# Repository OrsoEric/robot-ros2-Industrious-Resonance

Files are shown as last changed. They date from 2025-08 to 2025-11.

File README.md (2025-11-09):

# robot-ros2-Industrious-Resonance
Constructing a ROS2 robot to experiment with using LLMs as poors man AGI. 

# SPECS

- moving by sunday 2025-08-24 
- uses the raspberry pi
    - runs Ubuntu 22
    - runs ROS2
- uses OrangeHat
- uses 18650 battieries
- sensors
    - Raspicam
    - Microphone
- actuators    
    - two main motors
    - Loudspeaker
- options:
    - screen

# Old Robots

Census of old robots

## JetBot-00 (2021-09)

This is a robot I assembled to test the Jetson Nano.

It powered up, moved motors has screen and a supply. I should disassemble it, the Jetson Nano is too small to run competent AI with 2GB RAM. The Jetson Nano also uses a custom linux with binary blobs and not a real linux.

2021-09-JetBot-00-TOP

2021-09-JetBot-00-BOT

I can technically mount a raspberry and make a robot out of it.

## OrangeBot (2020-10)

Large robot for the Pi Wars with DC Motors with Encoders. It's high spec but not suitable for this project.

OrangeBot Pi Wars 2020

## Unnamed Lego Robot

This is a good effort to make a raspberry pi lego robot.

Unnamed Lego Robot

# ROBOT 

I choose to start from the LEGO robot, it should be very close to working

## Mechanical

Using OpenSCAD to design the base

### Ball Holder

As pivot wheel, I think of using a 40mm tennis ball. I can make a 3D printed structure to hold it with low friction, I'm thinking of three holding arms and three structural arms. I went with OpenSCAD to make it



https://github.com/user-attachments/assets/4e690c88-9136-435e-aecc-3a0f2ad5ae8a

### Servo Holder

I reused some of my previous work but decided I should do pillars without overhangs since I'm printing them on the robot platform



### Shell

Using Flux to generate possible images for the shell

Below is an idea I like that plays on the industrious resonance name, a shell that is weavy with interference patterns and a frontal lens

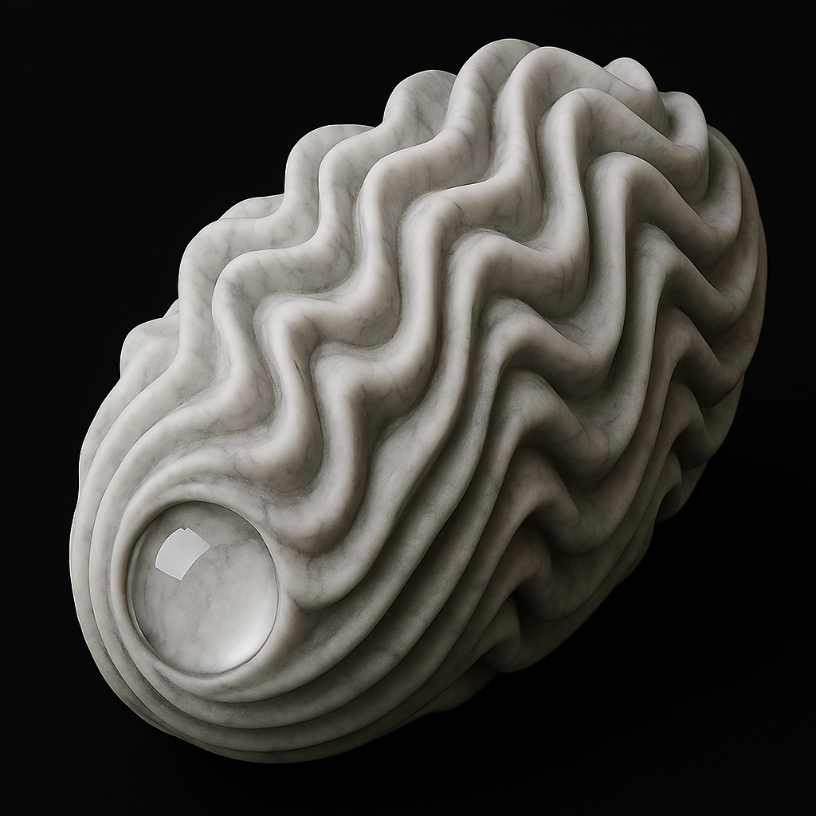
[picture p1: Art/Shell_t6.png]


### Platform



### Assembly 

Place a raspberry, batteries and servomotors on an ellipse



Considerations
- I switch to a Latte Panda MU to improve on LLM performance
- In the future I do a proper LPMU carry board
- I need to think of battery holder

Base is a rectangle with tounded corner. Developed servo pillars, used 18650 battery holder and ping pong ball holder for pivot.



With the Lattepanda Mu electronics on top and base properly resized to carry it



Considerations:
- Batteries are hard to reach, I'd like bottom facing battery holder, but how would supports work?
- I need a camara stand
- I need lips to attach a shell, or a border
- I need to decide on the electronics and spaces to platce that electronics
- I need to improve on the LPMU pillars, I need to make them through hole to the bottom
- I need a power switch

---

Lots of work on the robot
- 18650 inverse holder 2S2P, connected 4S1P
- border
- hole for switch
- support for regulator PCB
- hex nuts below for the lattepanda

I printed it in opaline PETG with supports, it came out really well! Tollerances for the battery holders are perfect!



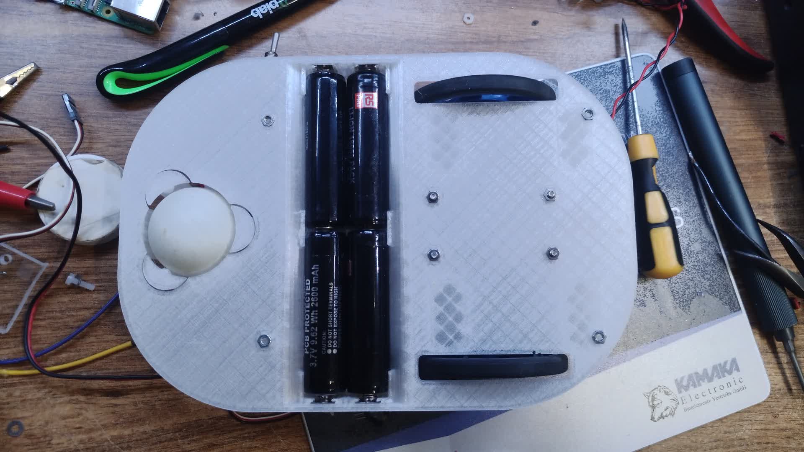
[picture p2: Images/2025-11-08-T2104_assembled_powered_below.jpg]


Video of the assembly Process

[Github is incompetently made and I have no way to embed a video bigger than 10MB](https://github.com/orgs/community/discussions/19403)

The video will work when you fork and open with VS Code with the preview MD. Otherwise download it and watch it.

[Link to the video of the assembly process of the battery and regulator](/Videos/2025-11-08-T2103_assembly_battery_regulator_480p.mp4)

## Electronics

### Raspberry Pi

It uses an OrangeHat, I remember it has a screen, UART, reset, and SERVO interpolation, it should be good to do a two axis rotation. It has an IMU, and the front numbers show change when I move it, it might be working!

I remember that if the OS isn't running, it keeps reset the OrangeHat and it stays offline, it's a deliberate design decision that works, it's why it wasn't showing anything.

Power regulator is good.

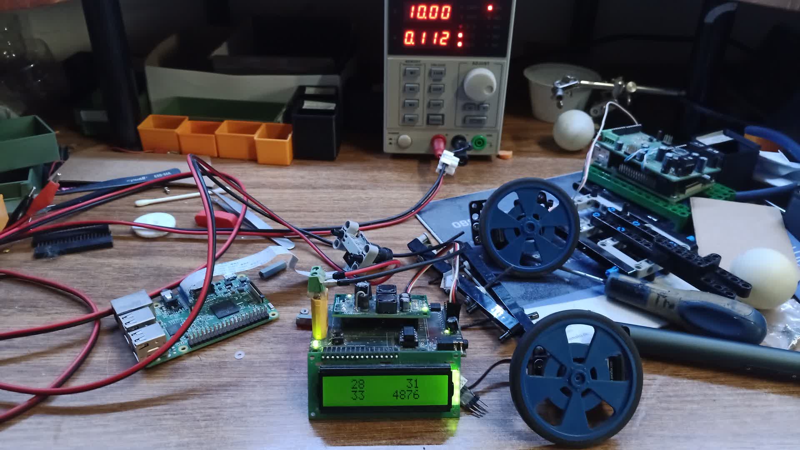
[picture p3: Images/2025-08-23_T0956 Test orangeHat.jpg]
Test OrangeHat Electronics


### Lattepanda Mu

Using the Lattepanda Mu I need a different electronics setup

I think I'll do a Longan Nano because of the screen, use one of my regulators, and an adapter to connect the servomotors. Feels like a good experimental setup without committing too much

I would like encoders on the motors...

### Servomotors - Longan Nano

I need a board to move the servomotors and have a screen.

First choice was the Longan Nano, it's compact, powerful and has a nice screen and I deed lots of drivers.

[Longan Nano](https://fatherofmachines.blogspot.com/p/longan-nano-gd32vf103.html)

I tried and it's bricked on Platform IO. I can probably make it work.

[](/log-longan-nano.md)

### Servomotors - AT324PA

I made useful boards based on AT324 and others, the one from Unit Zero has already the servo adapters and works fine.

[Install Microchip Studio](https://www.microchip.com/en-us/tools-resources/develop/microchip-studio#Downloads), open project, recompile and upload, everything works!

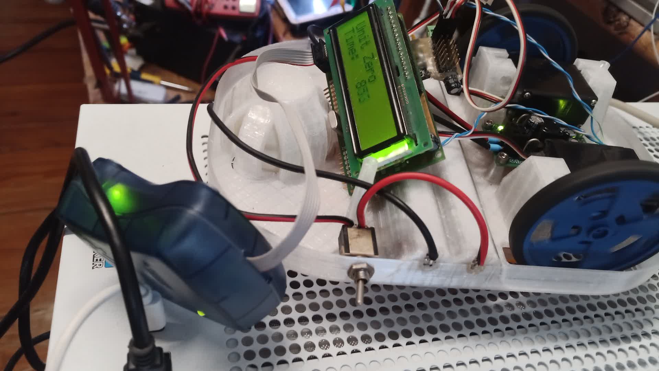
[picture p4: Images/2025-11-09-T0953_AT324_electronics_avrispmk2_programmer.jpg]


From here I need a firmware with the parser and uart in order to control it from an SBC

I'm thinking of doing it simple, possibly a mov speed duration instruction, that is very easy for the MCP server to produce, even if not very useful for doing useful applications. This is just an MVP.

## Firmware

SPECS:
- UART link
- Parser
- Ability to move servos
- Ability to display text on the screen

### Seesaw

Make a demo to move at seesaw speed the two wheels

<video src="https://github.com/user-attachments/assets/5bb4f36e-5e4b-4e43-b68f-162d931d1378" width="720" height="480"></video>

### Serial Commands

OrangeHat is programmed with the following functions

```
ARG_S8 = 's',
ARG_U8 = 'u',
ARG_S16 = 'S',
ARG_U16 = 'U',
ARG_U32 = 'D',
ARG_S32 = 'd'

//Register ping command. It's used to reset the communication timeout
f_ret = parser_tmp.add_cmd( "P", (void *)&ping_handler );
//Register the Find command. Board answers with board signature
f_ret |= parser_tmp.add_cmd( "F", (void *)&send_signature_handler );
//Platform set PPM command
f_ret |= parser_tmp.add_cmd( "PPM%u:%S:%S", (void *)&set_servo_ppm );
```

### Protocol

---

## Operating System and Raspicam Streaming

Now I need to choose a Raspberry and setup the OS.

I do have a Raspberry with Hailo 8L and raspiocam streaming already setup, test that instead, it saves lots of work!

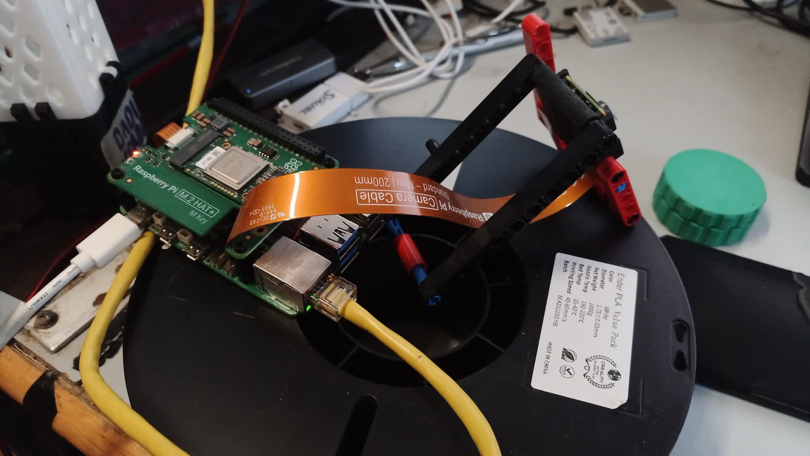
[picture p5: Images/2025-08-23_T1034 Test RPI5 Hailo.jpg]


Power is good, now try with ping, putty and launching the streaming demo and enumerating the Hailo

- ETH0 (static): 192.168.1.65 
- User: raspi
- Password: raspi

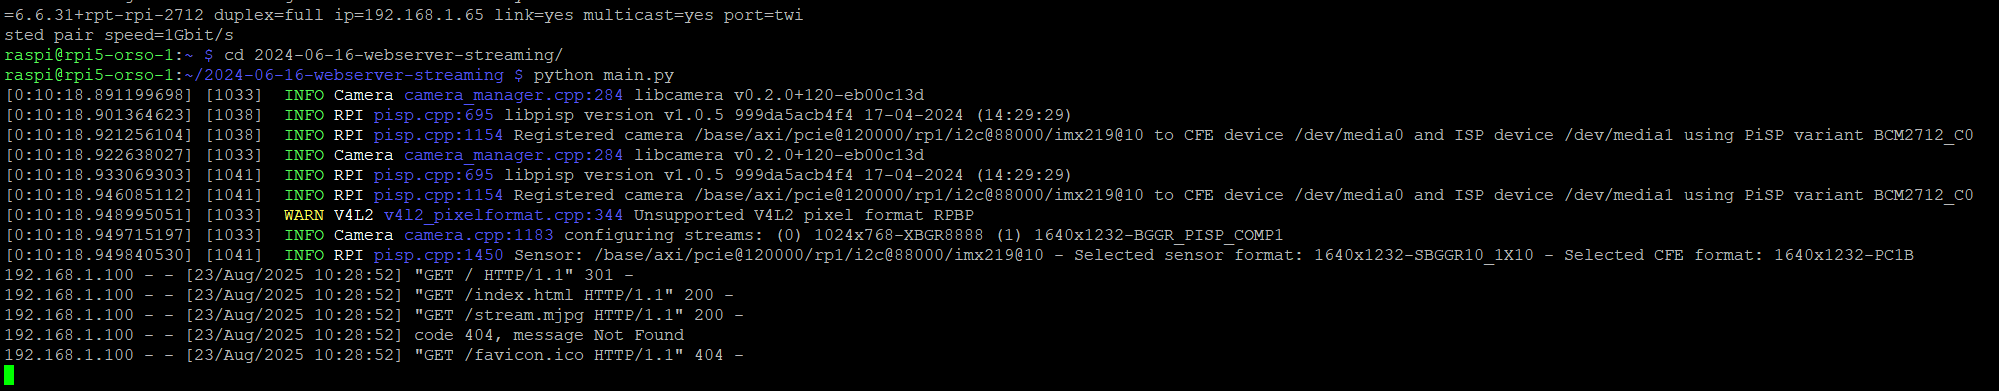
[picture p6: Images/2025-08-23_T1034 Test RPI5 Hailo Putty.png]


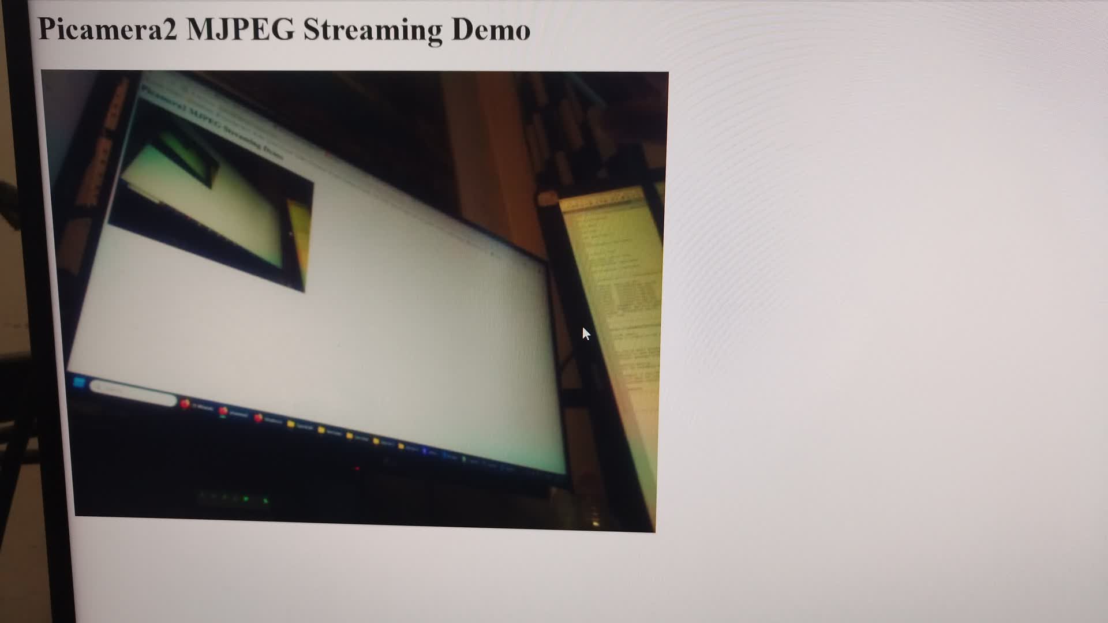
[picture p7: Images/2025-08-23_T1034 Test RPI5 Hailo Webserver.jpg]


TODO: Do I really want to move to Ubuntu and have ROS2? If I'm already good like this perhaps I should drop the ROS2 requirement

### Raspberry Pi 5

Test that the power supply is good
- 10V 0.5A streaming with camera and connected via webserver

Connect with VS Code Remote

Make an application that clears the reset

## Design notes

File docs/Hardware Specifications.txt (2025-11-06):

Mu Lite Board

Latte Panda Mu

N100
https://www.techpowerup.com/cpu-specs/processor-n100.c3007

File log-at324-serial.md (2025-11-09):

# Serial

Connecting the AT324 to the computer was more trouble than expected

Windows 11 is incompetently designed and doen't load the driver

Key registers didn't help, doesn't load the driver

Two of my adapters don't work

Luckily the FTDI 232 does have a WIN11 blessed driver

[Blessed driver for FTDI232](https://ftdichip.com/drivers/)

Connecting the AT324 to the robot regulator, the programmer, the scope and the FTDI chip to the computer. Using UART0 PD1 TXO to send



Checking with scope that it works



FTDI chip



Checking rx and tx. Sent SHAKA, and the firmware does send it back one at a time, I'm unloading it slowly for some reason, that's fine it's just done quick to work, the peripheral drivers I wrote a long while ago seems to work!



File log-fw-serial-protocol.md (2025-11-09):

# Serial Protocol

The scope of the protocol is to let the SBC send motion commands

It's meant to be compiled by a MCP server

So I'd like to have a sort of queue of commands, I am thinking speed duration

## Maze Runner

Below is the dictionary I used for Maze Runner

```cpp
//Command dictionary. Command IDs 0 and 255 are forbidden
U8 uart_cmd[] =
{
	//Ping: No action. Effect is to reset the connection timeout
	UART_CMD_PING		, 'P', '\0',
	//Sign: Ask for board signature
	UART_CMD_SIGN		, 'F', '\0',
	//Set Speed: R right engine L left engine
	UART_CMD_SETVEL	, 'V', 'R', '%', 'd', 'L', '%', 'd', '\0',
	//Dictionary terminator
	'\0'
};
//Board Signature
U8 *board_sign = (U8 *)"MazeRunner_05032";
```

In my uniparser, d is S32, so it's two S32 signed number this command, I send them to the board as bytes, not as ascii numbers

## Protocol

I need smaller numbers, I think I could do something like this

```cpp
//Command dictionary. Command IDs 0 and 255 are forbidden
U8 uart_cmd[] =
{
	//Ping: No action. Effect is to reset the connection timeout
	UART_CMD_PING		, 'P', '\0',
	//Sign: Ask for board signature
	UART_CMD_SIGN		, 'F', '\0',
    //Sign: Ask for firmware revision
	UART_CMD_REVISION	, 'REV', '\0',
    //STOP: set speed 0 to the motors
	UART_CMD_STOP		, 'STOP', '\0',
	//VELOCITY: R right engine L left engine (last forever until overwritten)
	UART_CMD_SET_VELOCITY     , 'V', 'R', '%', 's', 'L', '%', 's', '\0',
    //VELOCITY TIMED: R right engine L left engine T time of the motion
    UART_CMD_SET_VELOCITY_TIMED , 'V', 'R', '%', 's', 'L', '%', 's', 'T', '%', 'u', \0',
	//Dictionary terminator
	'\0'
};
//Board Signature
U8 *board_sign = (U8 *)"Industrious_Resonance";
//Firmware Revision
U8 *board_revision = (U8 *)"2025-11-09";
```

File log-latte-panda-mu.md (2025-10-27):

# Unboxing N305 16GB (2025-08-25)

Seems bricked. I can force the power rails of the lite board on, but there is a regulator on the Mu whose power rails never go up, no matter what.



# Unboxing N100 8GB (2025-09-20)

From Mouser got an N100 8GB, this powers on just fine and boots into a windows 11



Requires screen mouse and keyboard to operate

Screen I used the touch screen I built for the Jetson Nano 2GB robot a while ago.

I got some cheap NVME M.2 256GB PCIe 3.0 4X

I connected the ethernet, and it works just fine, no issues



Notice that there is no WiFI radio there. The board will make use of a M.2 wifi/bluetooth card. I could also use an ESP32 with AT commands.

# Install Ubuntu 24 LTS 

I'm going for a desktop ubuntu for now, since I'm debugging lots of things. I expect the software for the robot to use a ubuntu server instead. Also I plan to use a UART interface for ease.

Used Rufus to burn an ISO of Ubuntu 24 LTS for X86-64 AMD64

[Download ISO](https://ubuntu.com/download/desktop/thank-you?version=24.04.3&architecture=amd64&lts=true)

With the USB burned, go into the bios, and change boot order. My used NVME shows with a random linux burned on it, ignore it.



It's painless to install and boot into ubuntu, on the EMMC 64GB drive, and wipe windows out. Secure Boot was disabled, cart that it could cause issues if active and trying dual boot.



# Install Ubuntu Server 24 LTS

[Ubuntu Server 24 ISO Download](https://mirror.dogado.de/ubuntu-releases/24.04.3/ubuntu-24.04.3-live-server-amd64.iso)

Use RUFUS to burn USB key



Go into bios

Use keyboard and screen

# Format NVME

This being linux, it's not easy to format a drive and use it

My first attempt to format and add the drive, it has some issues like weird folder names

<details>
<summary>2025-09-20 LP NVME Setup</summary>

```
sudo umount /dev/nvme0n1

sudo mkfs.ext4 /nvme0n1

mount | grep ext4

ls -ld /media/sona/fe4d92e2-b743-4576-b445-e47f511902d0

sudo chown -R sona:sona /media/sona/

ls -ld /media/sona/fe4d92e2-b743-4576-b445-e47f511902d0

mkdir /media/sona/fe4d92e2-b743-4576-b445-e47f511902d0/models_llm

ls /media/sona/fe4d92e2-b743-4576-b445-e47f511902d0

```





</details>

New instructions

First enumerate drives

```
lsblk

sona@lpn10016gb:~$ lsblk
mmcblk0      179:0    0  58.2G  0 disk
├─mmcblk0p1  179:1    0     1G  0 part /boot/efi
└─mmcblk0p2  179:2    0  57.2G  0 part /
mmcblk0boot0 179:8    0     4M  1 disk
mmcblk0boot1 179:16   0     4M  1 disk
nvme0n1      259:0    0 238.5G  0 disk
```

Target is the 256GB drive root ```nvme0n1```

Now that drive needs to be formatted ext4, mounted, and given user permission to be used, then create a folder for LLM models so they reside on the external NVME drive and not the EMMC compute module drive

```
sudo umount /dev/nvme0n1

sudo mkfs.ext4 /nvme0n1

lsblk
```

Now create a folder where driver can be mounted and mount the drive

```
ls /mnt/

sudo mkdir /mnt/external_disk

ls /mnt/

sudo mount /dev/nvme0n1 /mnt/external_disk

ls /mnt/

df -h

sudo chown -R sona:sona /mnt/external_disk

touch /mnt/external_disk/test_file.txt

ls /mnt/external_disk/
```

<details>
<summary>2025-10-26 LP NVME Setup LOGS</summary>

```
sona@lpn10016gb:~$ lsblk
mmcblk0      179:0    0  58.2G  0 disk
├─mmcblk0p1  179:1    0     1G  0 part /boot/efi
└─mmcblk0p2  179:2    0  57.2G  0 part /
mmcblk0boot0 179:8    0     4M  1 disk
mmcblk0boot1 179:16   0     4M  1 disk
nvme0n1      259:0    0 238.5G  0 disk

sona@lpn10016gb:~$ sudo mkfs.ext4 /dev/nvme0n1
mke2fs 1.47.0 (5-Feb-2023)
/dev/nvme0n1 contains a ext4 file system
        created on Sun Oct 26 11:03:49 2025
Proceed anyway? (y,N) y
Discarding device blocks: done
Creating filesystem with 62514774 4k blocks and 15630336 inodes
Filesystem UUID: 7e68a2d7-b91a-4a03-bfe4-43aae9666b18
Superblock backups stored on blocks:
        32768, 98304, 163840, 229376, 294912, 819200, 884736, 1605632, 2654208,
        4096000, 7962624, 11239424, 20480000, 23887872

Allocating group tables: done
Writing inode tables: done
Creating journal (262144 blocks): done
Writing superblocks and filesystem accounting information: done

sona@lpn10016gb:~$ lsblk
NAME         MAJ:MIN RM   SIZE RO TYPE MOUNTPOINTS
mmcblk0      179:0    0  58.2G  0 disk
├─mmcblk0p1  179:1    0     1G  0 part /boot/efi
└─mmcblk0p2  179:2    0  57.2G  0 part /
mmcblk0boot0 179:8    0     4M  1 disk
mmcblk0boot1 179:16   0     4M  1 disk
nvme0n1      259:0    0 238.5G  0 disk

sona@lpn10016gb:~$ ls /mnt/

sona@lpn10016gb:~$ sudo mkdir /mnt/external_disk

sona@lpn10016gb:~$ ls /mnt/
external_disk

sona@lpn10016gb:~$ sudo mount /dev/nvme0n1 /mnt/external_disk

sona@lpn10016gb:~$ ls /mnt/
external_disk

sona@lpn10016gb:~$ df -h
Filesystem      Size  Used Avail Use% Mounted on
tmpfs           1.6G  1.7M  1.6G   1% /run
efivarfs        192K   85K  103K  46% /sys/firmware/efi/efivars
/dev/mmcblk0p2   56G  6.7G   47G  13% /
tmpfs           7.7G     0  7.7G   0% /dev/shm
tmpfs           5.0M     0  5.0M   0% /run/lock
/dev/mmcblk0p1  1.1G  6.2M  1.1G   1% /boot/efi
tmpfs           1.6G   12K  1.6G   1% /run/user/1000
/dev/nvme0n1    234G   28K  222G   1% /mnt/external_disk

sona@lpn10016gb:~$ sudo chown -R sona:sona /mnt/external_disk

sona@lpn10016gb:~$ touch /mnt/external_disk/test_file.txt

sona@lpn10016gb:~$ ls /mnt/external_disk/
lost+found  test_file.txt
```

</details>

With this now I have an external, big, fast drive where I can dump the LLM models

# LLM Inference

The big reason to use the Latte Panda Mu is because Intel, unlike every other manufacturer like AMD, makes drivers for their iGPU, meaning I can theoretically get great performance.

[LM Studio as appimage.](https://installers.lmstudio.ai/linux/x64/0.3.26-6/LM-Studio-0.3.26-6-x64.AppImage)

Now, this being linux, it's not easy to install.

- right click execution permission, or do chmod from command line
- it still fails because there aren't permissions on tmp files (???)
- reboot
- move appimage on a dedicated folder in home
- double click, now after a while it starts



Make sure to select the NVME as target folder for the LLMs, I had to redo it after boot, I am not sure why, but the model still works, LM Studio will find them as long as you select the correct folder where to search the models. I suspect user/media changes the hex hash? Not sure.



LM Studio being competently made, uses a llama cpp Vulkan runtime that works out of the box



Performance is around 3T/s in answer speed for Qwen 3 4B Q4M, I did expect it to be faster, but it's miles faster than a Pi would be, I'll do further testing.

With this 8GB model, I have 4GB allocated to the iGPU. In theory, 8B Q3 should run.

TODO: Test OpenVINO runtimes and ollama and raspberry for comparison

# Raspicam (FAIL)

The Latte Panda Mu has a MIPI CSI 2 interface. I connected the raspicam, and it doesn't boot. I was afraid of having bricked everything, but disconnecting the raspicam makes it boot.



# Remote Desktop (FAIL)

I want to remote into Ubuntu 24 on the LPMU

I tried to install install xrdp, and work out configuration to no avail. 



I think it's missing some shared objects? Not sure. I expected ubuntu to support remote desktop out of the box, and online guides have me install all sort of dependencies and open ports on the firewall that do not work. I can't connect.

# SSH

Again SSH didn't work out of the box, but it was easy to setup

```
sudo apt install openssh-server

sudo systemctl enable ssh

sudo systemctl status ssh

sudo ufw allow ssh

sudo reboot now

```

I can connect easily with Putty



# VS Code Remote

Having SSH and having VS Code, I can use my windows VS Code to develop and execute remotely code on the latte panda mu

- VS Code Remote
- On bottom left, there is the connect button
- On top center screen
- connect to host sona@192.168.1.239 
- it'll ask you linux continue, etc...
- if it fails, it's because windows is dumb and incompetent, and stores SSH key base on IP, so if your board moved to another IP, it'll fail. If so, go to user/you/.ssh and wipe the keys stored there known_host



On top left, you can open folder, and go to the home folder, and this way you have the terminal into the machine to execute python script, and the file explorer to create folders and script



# TODO

### Test UART Ports

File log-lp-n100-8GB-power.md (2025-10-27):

# Latte Panda N100 8GB Power

I connected the lapttepanda to a bench power supply, and I monitored the current used in various phases.

I'll do the same for raspberry pi 5.

I need to find the efficiency of the SBC running LLMs.

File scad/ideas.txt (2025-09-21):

I need a raspberry pi housing

I need 18650 battery slots

I need a raspicam holder

I need two servo brackets

I need a pivot ball

I'm thinking of hunyuan a star wars droid head

A sleek ellipsoidal shell with shifting fractal patterns interwoven with flowing waveforms; iridescent surfaces reflect deep blue and gold, glowing lines trace the fractal pathways, and smooth convex lenses sit at the front, radiating harmony between precision and infinite complexity.

I'll have the full might of Flux/HiDream/Qwen render it, then deploy the Hunyuan3D to make it 3D and have the shell of Industrious Resonance.

The LLM had a field day developing it, I used my novel prepront and made the whole backstory :D

I have a series of options for the battery
Down loading?
Vertical?
I can also do a boundary, and have side loading with sliding door?
But the contact?

Now, down loading with lid seems the most sensible option

With four or two batteries, the lid just needs metal tabs, but no wire, it just needs to connect two batteries

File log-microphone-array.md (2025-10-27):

# Microphone Array

The reason for a mic array, is to have improved sound detection to gove commands to the robot

[Seed Studio ReSpeaker 4 mic array](https://www.seeedstudio.com/ReSpeaker-USB-Mic-Array-p-4247.html)

In theory, the direction identification should also be useful detecting sounds

It has a DAC to connect the loudspeakers as well to do noice cancellation of the audio generated

# Latte Panda Mu

It worked immediately

I installed the sounde recorder from the store, and it just worked OOB



# CLI

```
mkdir test_microphone

```

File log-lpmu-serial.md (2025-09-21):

# Serial Ports

The Latte Panda Mu and the Lite Carrier boards have a number of serial interfaces

I need to find out how they are mapped to linux ubuntu and how to use them

# Dev Tree

```
sona@sona-lp-n100-8gb:~$ ls /dev/
autofs           i2c-7         nvme0     tty24  tty59      ttyS6
block            i2c-8         nvme0n1   tty25  tty6       ttyS7
btrfs-control    i2c-9         nvram     tty26  tty60      ttyS8
bus              initctl       port      tty27  tty61      ttyS9
char             input         ppp       tty28  tty62      udmabuf
console          kmsg          psaux     tty29  tty63      uhid
core             kvm           ptmx      tty3   tty7       uinput
cpu              log           pts       tty30  tty8       urandom
cpu_dma_latency  loop0         random    tty31  tty9       userfaultfd
cuse             loop1         rfkill    tty32  ttyprintk  userio
disk             loop10        rtc       tty33  ttyS0      vcs
dma_heap         loop11        rtc0      tty34  ttyS1      vcs1
dri              loop2         shm       tty35  ttyS10     vcs2
drm_dp_aux0      loop3         snapshot  tty36  ttyS11     vcs3
ecryptfs         loop4         snd       tty37  ttyS12     vcs4
fb0              loop5         stderr    tty38  ttyS13     vcs5
fd               loop6         stdin     tty39  ttyS14     vcs6
full             loop7         stdout    tty4   ttyS15     vcsa
fuse             loop8         tpm0      tty40  ttyS16     vcsa1
gpiochip0        loop9         tpmrm0    tty41  ttyS17     vcsa2
hidraw0          loop-control  tty       tty42  ttyS18     vcsa3
hidraw1          mapper        tty0      tty43  ttyS19     vcsa4
hpet             mcelog        tty1      tty44  ttyS2      vcsa5
hugepages        mei0          tty10     tty45  ttyS20     vcsa6
hwrng            mem           tty11     tty46  ttyS21     vcsu
i2c-0            mmcblk0       tty12     tty47  ttyS22     vcsu1
i2c-1            mmcblk0boot0  tty13     tty48  ttyS23     vcsu2
i2c-10           mmcblk0boot1  tty14     tty49  ttyS24     vcsu3
i2c-11           mmcblk0p1     tty15     tty5   ttyS25     vcsu4
i2c-12           mmcblk0p2     tty16     tty50  ttyS26     vcsu5
i2c-13           mmcblk0rpmb   tty17     tty51  ttyS27     vcsu6
i2c-14           mqueue        tty18     tty52  ttyS28     vfio
i2c-15           mtd           tty19     tty53  ttyS29     vga_arbiter
i2c-2            mtd0          tty2      tty54  ttyS3      vhci
i2c-3            mtd0ro        tty20     tty55  ttyS30     vhost-net
i2c-4            net           tty21     tty56  ttyS31     vhost-vsock
i2c-5            ng0n1         tty22     tty57  ttyS4      zero
i2c-6            null          tty23     tty58  ttyS5      zfs
```

ttySxxx should be serial interfaces, on the pi they are also mapped to ttyAMAxxx

```
PermissionError: [Errno 13] Permission denied: '/dev/ttyS1'

sona@sona-lp-n100-8gb:~$ ls -l /dev/ttyS0
crw-rw---- 1 root dialout 4, 64 Sep 21 09:09 /dev/ttyS0

```

permission for those ports is group dialout, so I add those permissions to my user

```
sudo usermod -a -G dialout $USER
sudo reboot
```

## Python

```
#!/usr/bin/python
#----------------------------------------------------------------
# IMPORTS
#----------------------------------------------------------------

import logging
import time
import serial
import struct

#----------------------------------------------------------------
# MAIN
#----------------------------------------------------------------

if __name__ == '__main__':
    # Initialize logs
    logging.basicConfig(
        level=logging.INFO,
        format='[%(asctime)s] %(levelname)s %(module)s:%(lineno)d > %(message)s ',
    )
    logging.info("Starting serial port scan")

    ln_working_ports = list()

    # Iterate through ttyS0 to ttyS30
    for port_num in range(31):
        port = f'/dev/ttyS{port_num}'
        try:
            logging.info(f"Attempting to open {port}")
            gcl_ser = serial.Serial(
                port=port,
                baudrate=115200,
                parity=serial.PARITY_NONE,
                stopbits=serial.STOPBITS_ONE,
                bytesize=serial.EIGHTBITS,
                timeout=0,
                write_timeout=1.0
            )
            gcl_ser.reset_input_buffer()
            gcl_ser.reset_output_buffer()
            logging.info(f"Successfully opened {port}")
            print(f"Serial: {gcl_ser}")

            x_continue = True
            while x_continue:
                if gcl_ser.is_open:
                    sb_message = f"TEST MESSAGE to port {port_num}"
                    print(f"SEND >{sb_message}<")
                    n_byte_sent = gcl_ser.write(sb_message.encode())
                    gcl_ser.close()

                    ln_working_ports.append(port_num)
                else:
                    x_continue = False
                    print("CLOSED")
                time.sleep(0.5)

        except serial.SerialException as e:
            logging.error(f"Failed to open {port}: {e}")
            if gcl_ser and gcl_ser.is_open:
                gcl_ser.close()
            continue

    print(f"Working ports: {ln_working_ports}")

``` 

With permissions solved, modify the script to scan the ports

```
sona@sona-lp-n100-8gb:~$ python3 Projects/test_serial.py 
[2025-09-21 13:12:10,196] INFO test_serial:21 > Starting serial port scan 
[2025-09-21 13:12:10,196] INFO test_serial:29 > Attempting to open /dev/ttyS0 
[2025-09-21 13:12:10,196] INFO test_serial:41 > Successfully opened /dev/ttyS0 
Serial: Serial<id=0x735859b30580, open=True>(port='/dev/ttyS0', baudrate=115200, bytesize=8, parity='N', stopbits=1, timeout=0, xonxoff=False, rtscts=False, dsrdtr=False)
SEND >TEST MESSAGE to port 0<
CLOSED
[2025-09-21 13:12:11,200] INFO test_serial:29 > Attempting to open /dev/ttyS1 
[2025-09-21 13:12:11,201] ERROR test_serial:59 > Failed to open /dev/ttyS1: Could not configure port: (5, 'Input/output error') 
[2025-09-21 13:12:11,201] INFO test_serial:29 > Attempting to open /dev/ttyS2 
[2025-09-21 13:12:11,201] ERROR test_serial:59 > Failed to open /dev/ttyS2: Could not configure port: (5, 'Input/output error') 
[2025-09-21 13:12:11,201] INFO test_serial:29 > Attempting to open /dev/ttyS3 
[2025-09-21 13:12:11,201] ERROR test_serial:59 > Failed to open /dev/ttyS3: Could not configure port: (5, 'Input/output error') 
[2025-09-21 13:12:11,201] INFO test_serial:29 > Attempting to open /dev/ttyS4 
[2025-09-21 13:12:11,202] INFO test_serial:41 > Successfully opened /dev/ttyS4 
Serial: Serial<id=0x735859a901f0, open=True>(port='/dev/ttyS4', baudrate=115200, bytesize=8, parity='N', stopbits=1, timeout=0, xonxoff=False, rtscts=False, dsrdtr=False)
SEND >TEST MESSAGE to port 4<
CLOSED
[2025-09-21 13:12:12,206] INFO test_serial:29 > Attempting to open /dev/ttyS5 
[2025-09-21 13:12:12,207] INFO test_serial:41 > Successfully opened /dev/ttyS5 
Serial: Serial<id=0x735859a8cd90, open=True>(port='/dev/ttyS5', baudrate=115200, bytesize=8, parity='N', stopbits=1, timeout=0, xonxoff=False, rtscts=False, dsrdtr=False)
SEND >TEST MESSAGE to port 5<
CLOSED
[2025-09-21 13:12:13,212] INFO test_serial:29 > Attempting to open /dev/ttyS6 
[2025-09-21 13:12:13,212] INFO test_serial:41 > Successfully opened /dev/ttyS6 
Serial: Serial<id=0x735859a8cf10, open=True>(port='/dev/ttyS6', baudrate=115200, bytesize=8, parity='N', stopbits=1, timeout=0, xonxoff=False, rtscts=False, dsrdtr=False)
SEND >TEST MESSAGE to port 6<
CLOSED
[2025-09-21 13:12:14,218] INFO test_serial:29 > Attempting to open /dev/ttyS7 
[2025-09-21 13:12:14,218] ERROR test_serial:59 > Failed to open /dev/ttyS7: Could not configure port: (5, 'Input/output error') 
[2025-09-21 13:12:14,219] INFO test_serial:29 > Attempting to open /dev/ttyS8 
[2025-09-21 13:12:14,219] ERROR test_serial:59 > Failed to open /dev/ttyS8: Could not configure port: (5, 'Input/output error') 
[2025-09-21 13:12:14,219] INFO test_serial:29 > Attempting to open /dev/ttyS9 
[2025-09-21 13:12:14,219] ERROR test_serial:59 > Failed to open /dev/ttyS9: Could not configure port: (5, 'Input/output error') 
[2025-09-21 13:12:14,220] INFO test_serial:29 > Attempting to open /dev/ttyS10 
[2025-09-21 13:12:14,220] ERROR test_serial:59 > Failed to open /dev/ttyS10: Could not configure port: (5, 'Input/output error') 
[2025-09-21 13:12:14,220] INFO test_serial:29 > Attempting to open /dev/ttyS11 
[2025-09-21 13:12:14,220] ERROR test_serial:59 > Failed to open /dev/ttyS11: Could not configure port: (5, 'Input/output error') 
[2025-09-21 13:12:14,220] INFO test_serial:29 > Attempting to open /dev/ttyS12 
[2025-09-21 13:12:14,221] ERROR test_serial:59 > Failed to open /dev/ttyS12: Could not configure port: (5, 'Input/output error') 
[2025-09-21 13:12:14,221] INFO test_serial:29 > Attempting to open /dev/ttyS13 
[2025-09-21 13:12:14,221] ERROR test_serial:59 > Failed to open /dev/ttyS13: Could not configure port: (5, 'Input/output error') 
[2025-09-21 13:12:14,221] INFO test_serial:29 > Attempting to open /dev/ttyS14 
[2025-09-21 13:12:14,222] ERROR test_serial:59 > Failed to open /dev/ttyS14: Could not configure port: (5, 'Input/output error') 
[2025-09-21 13:12:14,222] INFO test_serial:29 > Attempting to open /dev/ttyS15 
[2025-09-21 13:12:14,222] ERROR test_serial:59 > Failed to open /dev/ttyS15: Could not configure port: (5, 'Input/output error') 
[2025-09-21 13:12:14,222] INFO test_serial:29 > Attempting to open /dev/ttyS16 
[2025-09-21 13:12:14,222] ERROR test_serial:59 > Failed to open /dev/ttyS16: Could not configure port: (5, 'Input/output error') 
[2025-09-21 13:12:14,222] INFO test_serial:29 > Attempting to open /dev/ttyS17 
[2025-09-21 13:12:14,223] ERROR test_serial:59 > Failed to open /dev/ttyS17: Could not configure port: (5, 'Input/output error') 
[2025-09-21 13:12:14,223] INFO test_serial:29 > Attempting to open /dev/ttyS18 
[2025-09-21 13:12:14,223] ERROR test_serial:59 > Failed to open /dev/ttyS18: Could not configure port: (5, 'Input/output error') 
[2025-09-21 13:12:14,223] INFO test_serial:29 > Attempting to open /dev/ttyS19 
[2025-09-21 13:12:14,223] ERROR test_serial:59 > Failed to open /dev/ttyS19: Could not configure port: (5, 'Input/output error') 
[2025-09-21 13:12:14,223] INFO test_serial:29 > Attempting to open /dev/ttyS20 
[2025-09-21 13:12:14,223] ERROR test_serial:59 > Failed to open /dev/ttyS20: Could not configure port: (5, 'Input/output error') 
[2025-09-21 13:12:14,223] INFO test_serial:29 > Attempting to open /dev/ttyS21 
[2025-09-21 13:12:14,223] ERROR test_serial:59 > Failed to open /dev/ttyS21: Could not configure port: (5, 'Input/output error') 
[2025-09-21 13:12:14,223] INFO test_serial:29 > Attempting to open /dev/ttyS22 
[2025-09-21 13:12:14,223] ERROR test_serial:59 > Failed to open /dev/ttyS22: Could not configure port: (5, 'Input/output error') 
[2025-09-21 13:12:14,223] INFO test_serial:29 > Attempting to open /dev/ttyS23 
[2025-09-21 13:12:14,223] ERROR test_serial:59 > Failed to open /dev/ttyS23: Could not configure port: (5, 'Input/output error') 
[2025-09-21 13:12:14,223] INFO test_serial:29 > Attempting to open /dev/ttyS24 
[2025-09-21 13:12:14,223] ERROR test_serial:59 > Failed to open /dev/ttyS24: Could not configure port: (5, 'Input/output error') 
[2025-09-21 13:12:14,223] INFO test_serial:29 > Attempting to open /dev/ttyS25 
[2025-09-21 13:12:14,223] ERROR test_serial:59 > Failed to open /dev/ttyS25: Could not configure port: (5, 'Input/output error') 
[2025-09-21 13:12:14,224] INFO test_serial:29 > Attempting to open /dev/ttyS26 
[2025-09-21 13:12:14,224] ERROR test_serial:59 > Failed to open /dev/ttyS26: Could not configure port: (5, 'Input/output error') 
[2025-09-21 13:12:14,224] INFO test_serial:29 > Attempting to open /dev/ttyS27 
[2025-09-21 13:12:14,224] ERROR test_serial:59 > Failed to open /dev/ttyS27: Could not configure port: (5, 'Input/output error') 
[2025-09-21 13:12:14,224] INFO test_serial:29 > Attempting to open /dev/ttyS28 
[2025-09-21 13:12:14,224] ERROR test_serial:59 > Failed to open /dev/ttyS28: Could not configure port: (5, 'Input/output error') 
[2025-09-21 13:12:14,224] INFO test_serial:29 > Attempting to open /dev/ttyS29 
[2025-09-21 13:12:14,224] ERROR test_serial:59 > Failed to open /dev/ttyS29: Could not configure port: (5, 'Input/output error') 
[2025-09-21 13:12:14,224] INFO test_serial:29 > Attempting to open /dev/ttyS30 
[2025-09-21 13:12:14,224] ERROR test_serial:59 > Failed to open /dev/ttyS30: Could not configure port: (5, 'Input/output error') 
Working ports: [0, 4, 5, 6]

```

I was able to open with success: 

```
Working ports: [0, 4, 5, 6]
```

Now I can make a script to send data through those ports, and see with an oscilloscope if something goes through

# Python Send

Script to send messages via serial interface. Change the port number to the ones found above.

```
#!/usr/bin/python
#----------------------------------------------------------------
# IMPORTS
#----------------------------------------------------------------

import logging
import time
import serial
import struct

#Measure TX, RX is the same port

#THis port is marked Debug on the lite board
N_PORT = 0

#near the CR battery, marked 0
#N_PORT = 4

#near the CR battery, marked 1
#N_PORT = 5

#near the CR battery, marked 2
#N_PORT = 6

#----------------------------------------------------------------
# MAIN
#----------------------------------------------------------------

if __name__ == '__main__':
    # Initialize logs
    logging.basicConfig(
        level=logging.INFO,
        format='[%(asctime)s] %(levelname)s %(module)s:%(lineno)d > %(message)s ',
    )
    logging.info("Send")

    n_cnt = 0

    port = f'/dev/ttyS{N_PORT}'
    try:
        logging.info(f"Attempting to open {port}")
        gcl_ser = serial.Serial(
            port=port,
            baudrate=115200,
            parity=serial.PARITY_NONE,
            stopbits=serial.STOPBITS_ONE,
            bytesize=serial.EIGHTBITS,
            timeout=0,
            write_timeout=1.0
        )
        gcl_ser.reset_input_buffer()
        gcl_ser.reset_output_buffer()
        logging.info(f"Successfully opened {port}")

        x_continue = True
        while x_continue:
            if gcl_ser.is_open:
                sb_message = f"TEST MESSAGE >{n_cnt}<"
                n_cnt = n_cnt +1
                print(f"SEND >{sb_message}<")
                n_byte_sent = gcl_ser.write(sb_message.encode())

            else:
                print("CLOSED")
                x_continue = False
            time.sleep(0.5)

    except serial.SerialException as e:
        logging.error(f"Failed to open {port}: {e}")
        if gcl_ser and gcl_ser.is_open:
            gcl_ser.close()

```

# Oscilloscope

Now that I found responsive ports, I use an oscilloscope to measure where the signals come out.

I setup the 10X attenuation on the probe, I use the yellow wire of the fan to see if the scope works. I activate the serial decoder, and tune it to scale when I found it. Remember that idle is high.

Then I probe the TX pins, and voila, they are all there!

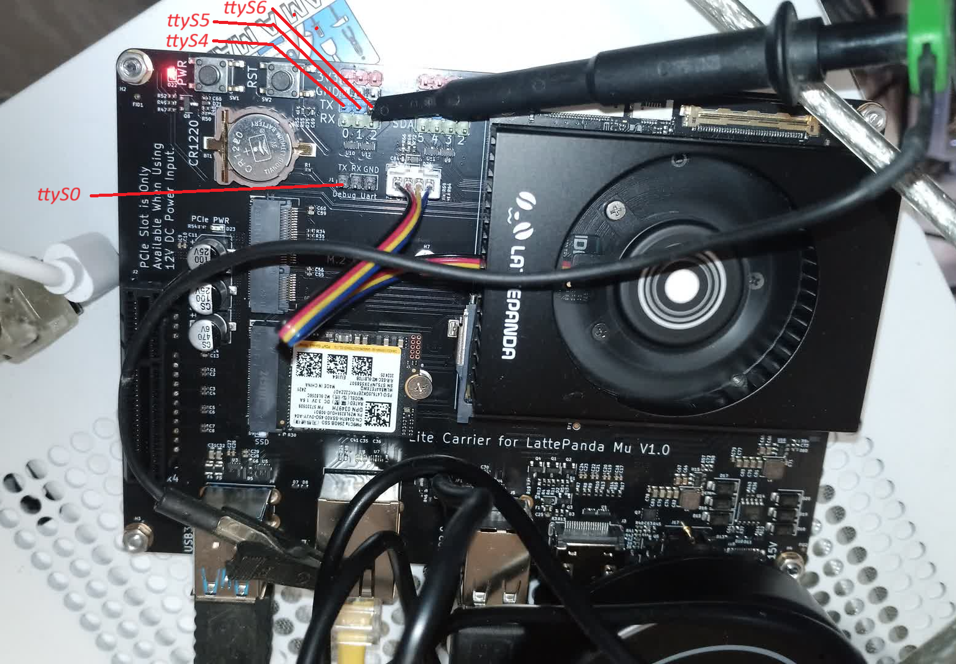
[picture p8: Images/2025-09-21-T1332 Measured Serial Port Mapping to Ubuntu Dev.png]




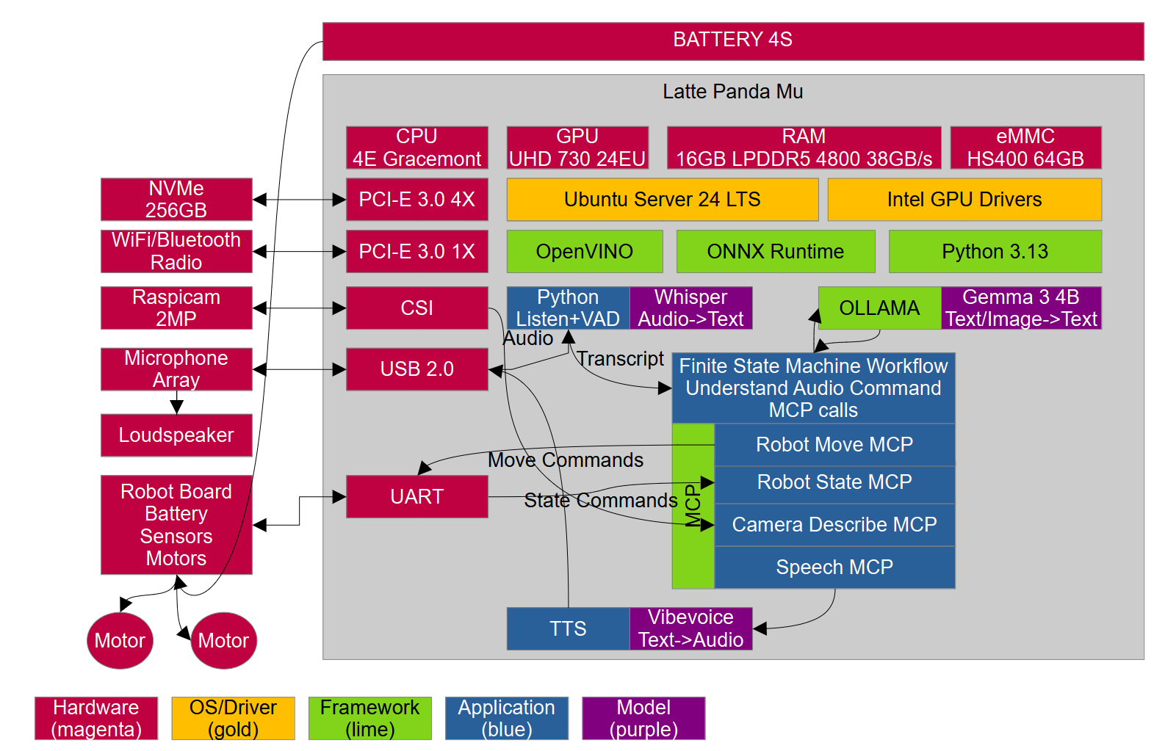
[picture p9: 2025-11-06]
docs/InRi Architecture.png

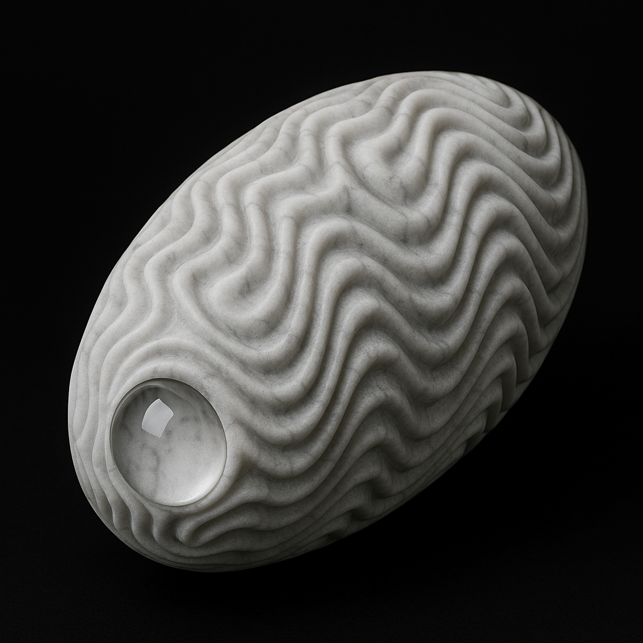
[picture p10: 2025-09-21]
Art/Shell_t5.png

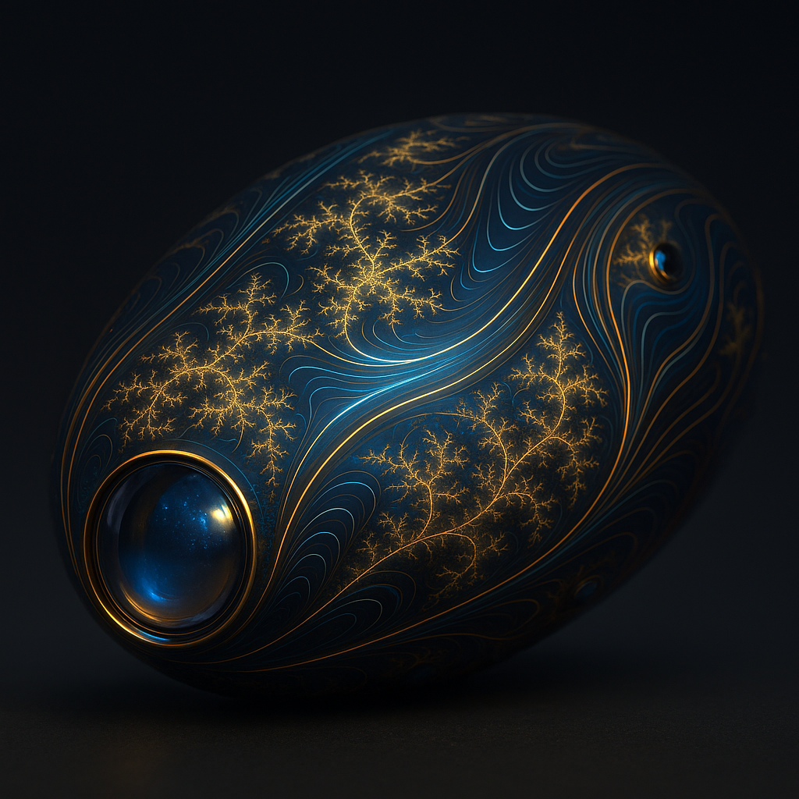
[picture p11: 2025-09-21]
Art/Shell_t1.png

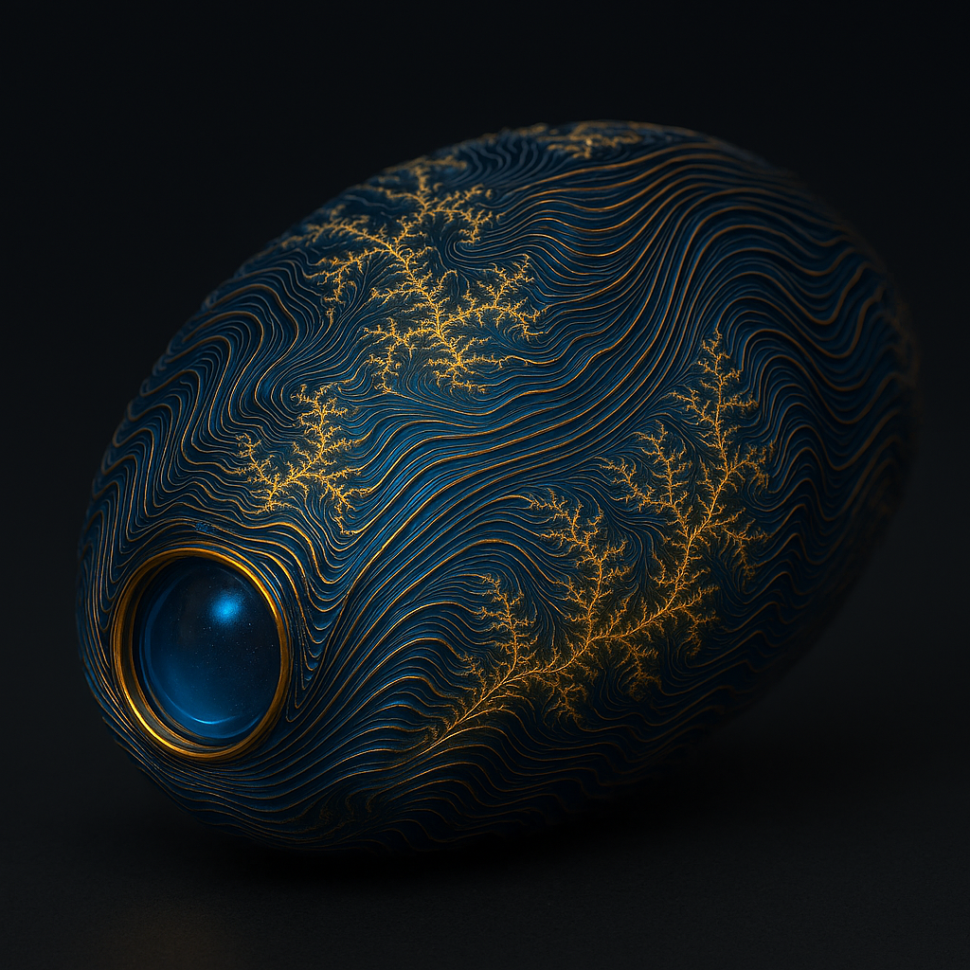
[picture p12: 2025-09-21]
Art/Shell_t2.png

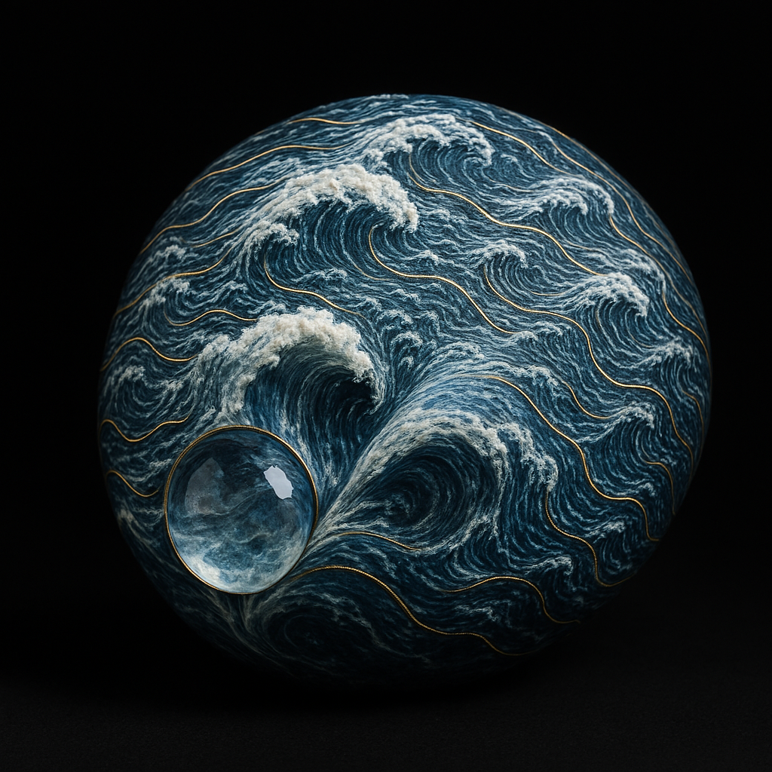
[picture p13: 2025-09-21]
Art/Shell_t4.png

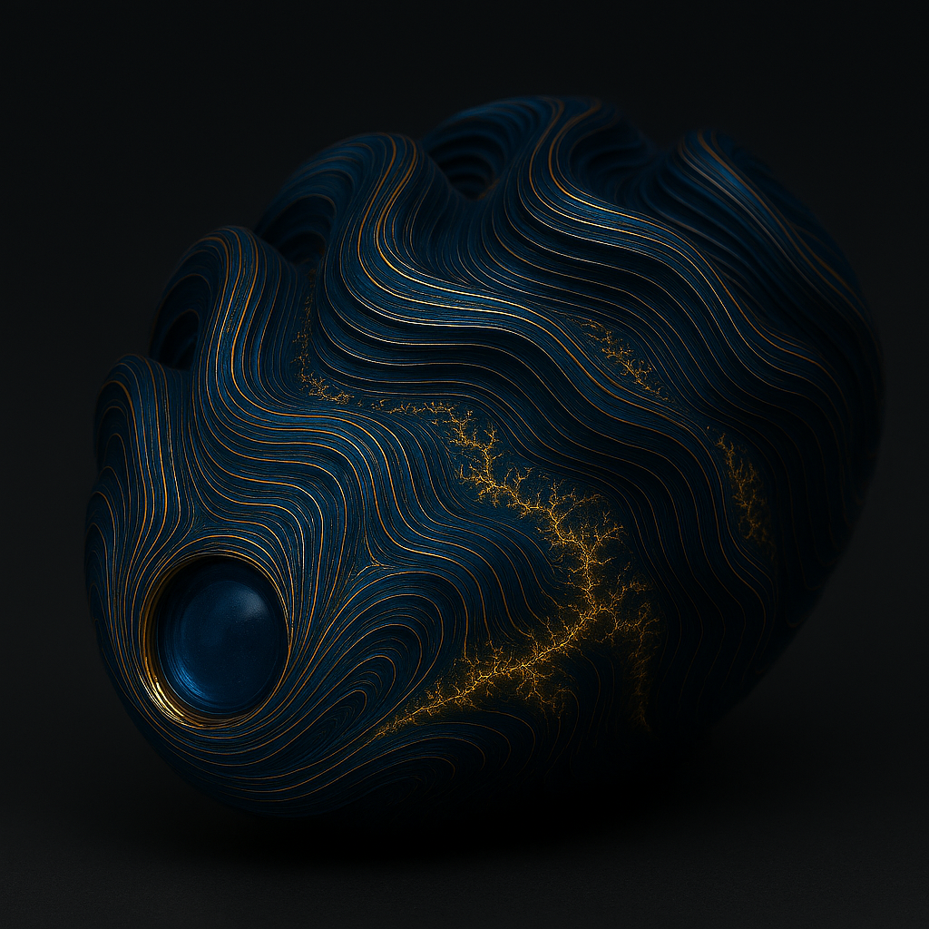
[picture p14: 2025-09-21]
Art/Shell_t3.png

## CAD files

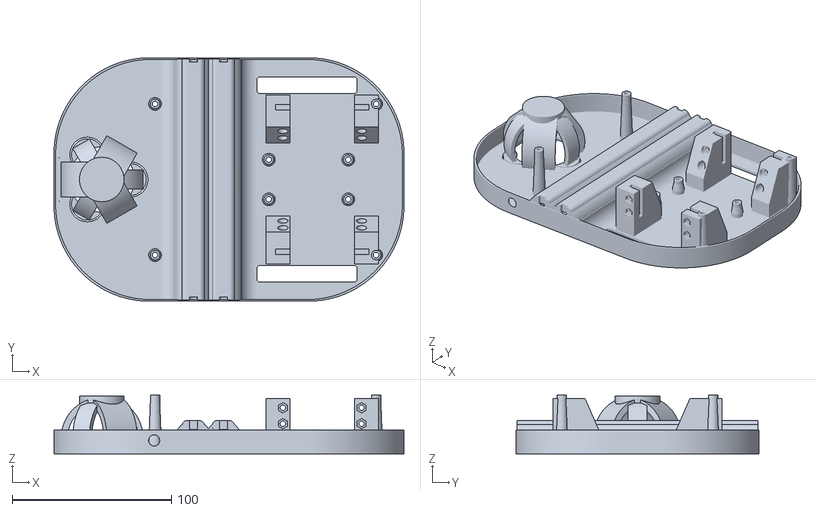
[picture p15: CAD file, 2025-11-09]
stl/2025-11-08-T1355_robot.stl
220.0 x 153.0 x 37.0

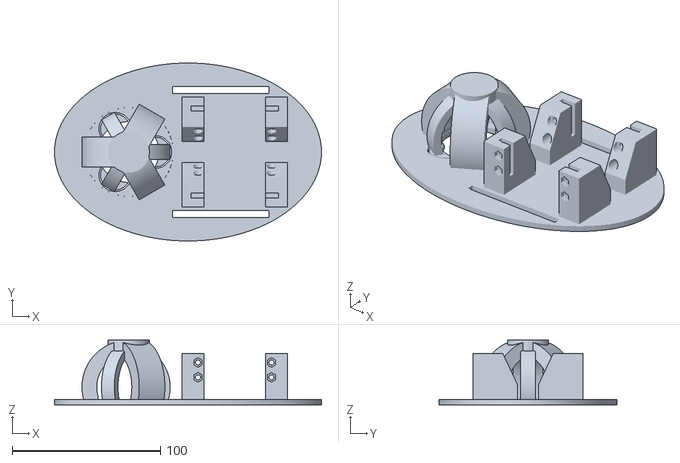
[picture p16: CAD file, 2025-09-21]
stl/test-hull-norpi-nobat-a.stl
180.0 x 120.0 x 43.5

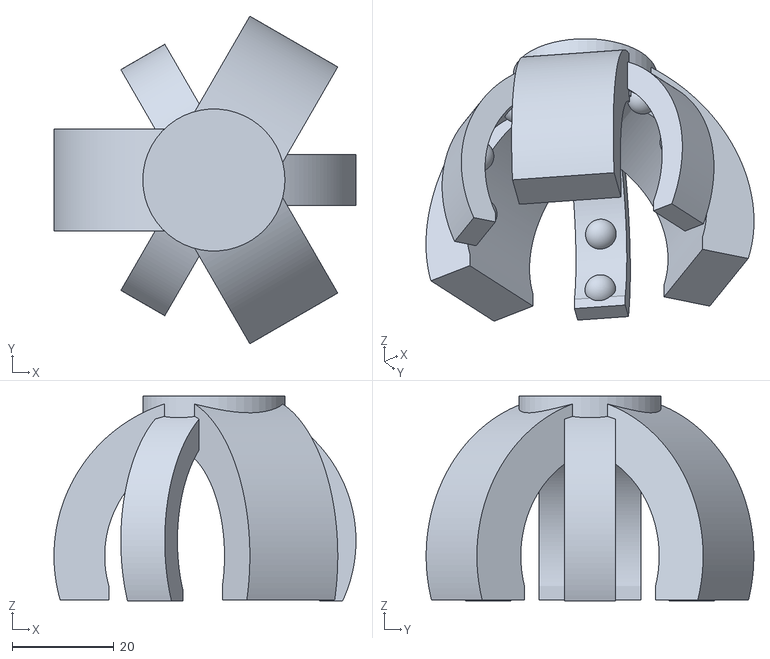
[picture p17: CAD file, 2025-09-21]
stl/2025-08-27_T1046_test-ball-holder-40mm.stl
59.5 x 64.6 x 40.3

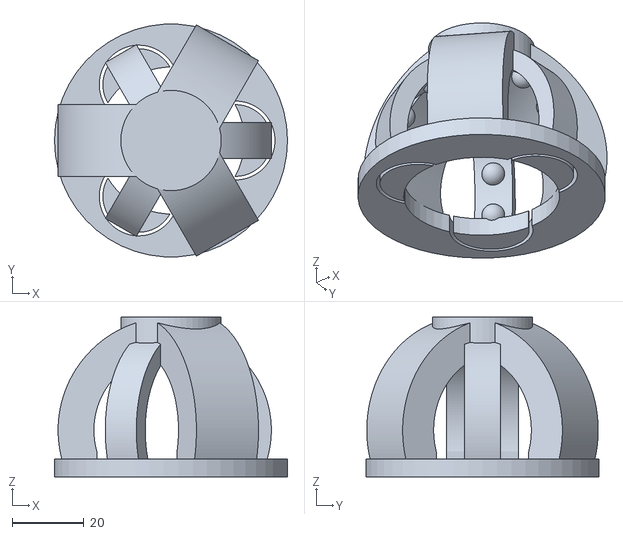
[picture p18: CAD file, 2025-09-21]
stl/2025-08-27_T1304_test-ball-holder-40mm.stl
65.0 x 64.9 x 44.5

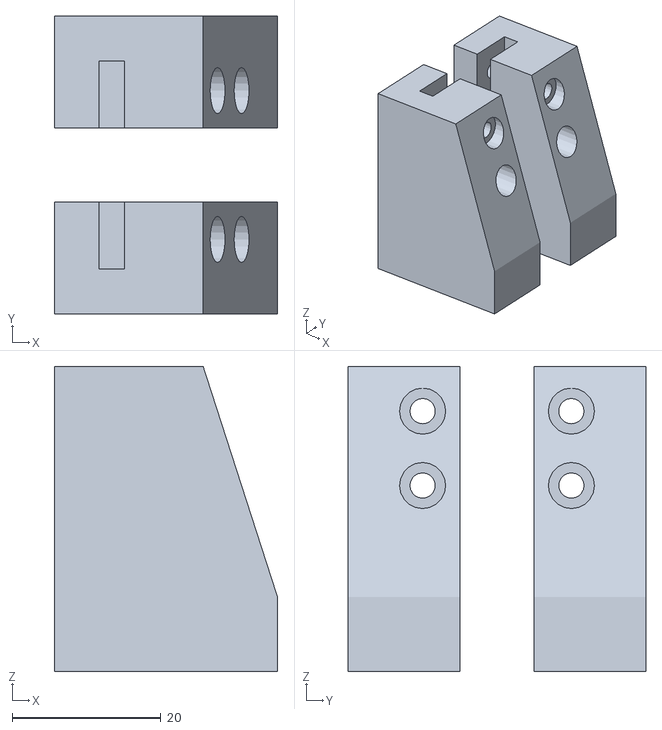
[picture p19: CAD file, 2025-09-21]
stl/test_servo_holder_a.stl
30.0 x 40.0 x 41.0

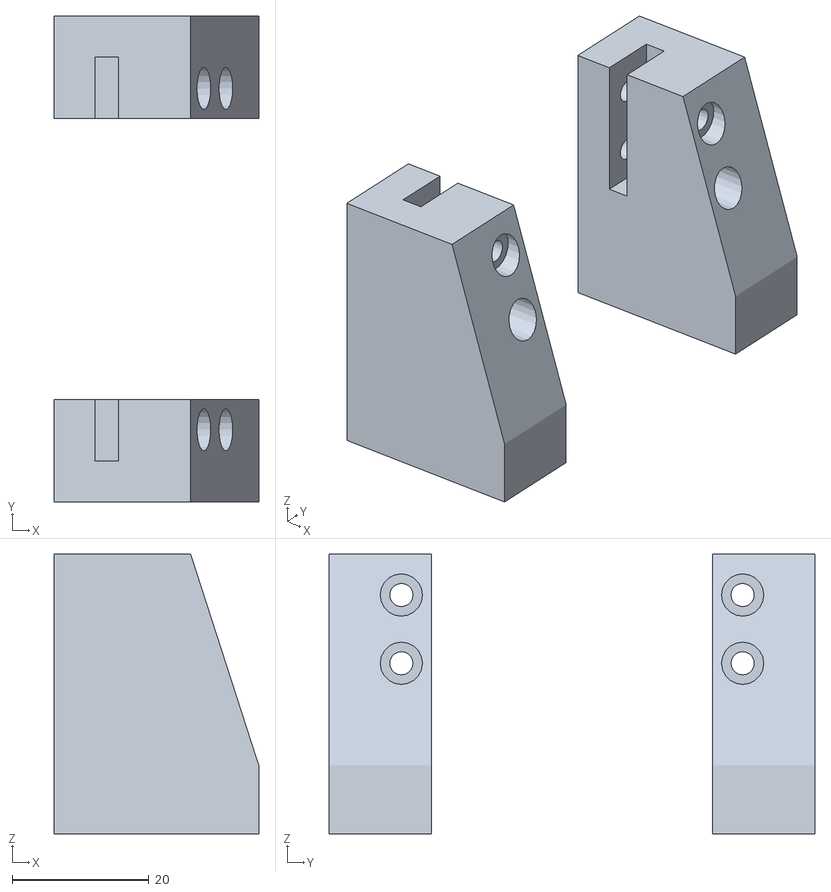
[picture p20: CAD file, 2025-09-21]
stl/test_servo_holder_b.stl
30.0 x 71.2 x 41.0

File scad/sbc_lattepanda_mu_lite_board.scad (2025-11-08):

include <libs/shape_cylinder.scad>

g_l_lpmu = 146;
g_w_lpmu = 102;
g_li_lpmu_hole = 139;
g_wi_lpmu_hole = 95;

module sbc_lattepanda_mu_lite_board
(
	//Green PCB dimensions
	i_l_pcb = 146,
	i_w_pcb = 102,
	i_t_pcb = 3,
	//Holes interaxis
	i_l_hole = 139, 
	i_w_hole = 95,
	i_d_hole = 3,
	//Ports
	i_l_port = 120,
	i_w_port = 30,
	i_h_port = 20,
	//SoC
	i_l_soc = 70,
	i_w_soc = 60,
	i_h_soc = 60,

	dummy
)
{
	translate
	([
		-i_l_pcb / 2,
		-i_w_pcb / 2,
		0
	])
	difference()
	{
		//Positive geometry
		union()
		{
			//PCB
			color("#00ff00")
			cube
			([
				i_l_pcb,
				i_w_pcb,
				i_t_pcb
			]);

			//ports
			color("#333333")
			translate
			([
				i_l_pcb / 2 - i_l_port / 2,
				0,
				0
			])
			cube
			([
				i_l_port,
				i_w_port,
				i_h_port
			]);

			//SoC
			color("#333333")
			translate
			([
				i_l_pcb -i_l_soc -10,
				i_w_pcb -i_w_soc -0,
				0
			])
			cube
			([
				i_l_soc,
				i_w_soc,
				i_h_soc
			]);

		} //Positive geometry
		//Negative Geometry
		union()
		{
			//PCB drill
			for (ol = [-i_l_hole/2, i_l_hole/2])
			for (ow = [-i_w_hole/2, i_w_hole/2])
			{
				translate
				([
					i_l_pcb/2 + ol,
					i_w_pcb/2 + ow,
					0
				])
				shape_cylinder
				(
					i_d = i_d_hole,
					i_h = i_t_pcb,
					i_e = 0.01
				);
			}

		} //Negative Geometry
	}	//Difference
}

if (false)
sbc_lattepanda_mu_lite_board();

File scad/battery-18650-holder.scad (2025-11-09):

include <libs/polyround.scad>

include <libs/shape_petal.scad>

include <battery-18650.scad>

//Include the geometry for the tab that contact with the battery, and the endcap of the battery holder
include <battery-18650-tabs.scad>

//	2024-06-23
//	Printed but too short for the batteries

//ia_section = controls the strength of the support. 0 is none. 90 comes up to half battery. the more up the more it retains, but the harder it is to insert
//Fixed the shape of the base to be more scalable with wall thickness, now works from 1 to 3
module half_support_18650
(
	ir_inner,
	ir_thickness,
	il_support,
	ia_section
)
{
    aan_points =
	([
        //Origin
        [0,0,0],
        [0,ir_thickness,0],
		[-ir_inner*0.5 -ir_thickness*0.7,ir_thickness,3],
        [-ir_inner*0.6 -ir_thickness*0.9,-0.2*ir_inner,0],
		[-ir_inner*0.3 -ir_thickness*0.4,-0.0*ir_inner,0],
        [-ir_inner*0.5 -ir_thickness*0.7,-0.0*ir_inner,0],
    ]);  

    //Place the base under the battery housing
    translate([0,0,ir_thickness])
    rotate([-90,0,-90])
    //Construct base
    linear_extrude(il_support)
    polygon(polyRound(aan_points,100));

	shape_petal
	(
		i_r_inner = ir_inner,
		i_r_thickness = ir_thickness,
		i_l_length =il_support,
		i_a_angle = ia_section,
		i_e = 0.01
	);
}

if (false)
half_support_18650
(
	ir_inner = (18.4+0.5)/2,
	ir_thickness = 1.0,
	il_support = 20,
	ia_section = 60
);


//Support around a full battery
module full_support_18650
(
	ir_inner,
	ir_thickness,
	il_support,
	ia_section,
)
{
    half_support_18650(ir_inner, ir_thickness, il_support, ia_section);

    //left wing
    translate([il_support,0,0])
    rotate([0,0,180])
    half_support_18650(ir_inner, ir_thickness, il_support, ia_section);
}

//Support around a full battery
module full_support_18650_asymmetric
(
	ir_inner,
	ir_thickness,
	il_support,
	ia_section_right,
	ia_section_left
)
{
    half_support_18650(ir_inner, ir_thickness, il_support, ia_section_right);

    //left wing
    translate([il_support,0,0])
    rotate([0,0,180])
    half_support_18650(ir_inner, ir_thickness, il_support, ia_section_left);
}

//Instance holder for a signle 18650 battery
module holder_18650_1s1p
(
	//	BATTERY
	//Diameter of the 18650 battery plus tollerance
	id_18650 = 18.4+0.5,
	//Length of the 18650 battery from base to button
	il_18650 = 71.0,

	//	TAB SPRING/BUTTON
	//Dimensions of the tab plate, plus tollerance
	il_tab = 11.0 +0.5,
	iw_tab = 11.0 +0.5,
	//Thickness of plate slot
	it_tab = 1.25,
	//Size of the button of the tab
	it_tab_button_positive = 1.5,
	//Length of the tab spring, uncompressed
	il_tab_spring_unloaded = 8.0,
	//Length of the tab spring, fully compressed
	il_tab_spring_loaded = 3.0,
	//How much to compress the spring 0 = unloaded, 1 = loaded
	ilk_tab_spring_compression = 0.75,
	//Rails
	iw_tab_rail = 1.75,

	//	STRUCTURE
	//Thickness of the Holder walls
	it_wall = 2.0,
	//Length factor of the wings 10 means 1/10 of length. 5 mean 1/5 of length
	ilk_wing = 6,


	//Angle of the cradle where the battery rests
	ia_cradle = 90,
	//Angle of the wings keeping the battery in place
	ia_wing = 110,
	
	//Thickness of the cap plus rails
	it_cap = 4.0,
	//thickness of the cap back
	it_cap_back = 2.0,
	


	//	WIRE
	//Lentgh of the wire slot
	il_slot_wire = 6,
	//Width of the wire slot
	iw_slot_wire = 5,

	//	SHOW EXTRA ELEMENTS
	//Show the battery model
	ix_show_battery = false,
	//Show battery tab spring
	ix_show_tab = false
)
{
    nl_base = 50;

	//Compute the spring compression length when battery is placed
	il_tab_spring = il_tab_spring_loaded + (il_tab_spring_unloaded -il_tab_spring_loaded)*(1-ilk_tab_spring_compression);
	
	echo("Spring loading",il_tab_spring);
	//Total length of the battery holder. account for the full stack
	l_total = il_18650 + it_cap_back + it_tab_button_positive + il_tab_spring + it_cap_back;

    //battery
    if (ix_show_battery == true)
    {
        //translate([(l_total-il_18650)/2,0,it_wall])
		translate([it_cap_back+it_tab_button_positive,0,it_wall])
        battery_18650
		(
			// Barrel Dimensions
			i_l_18650 = il_18650,
			i_d_18650 = id_18650-0.5,
			ix_sideway = 1,
			in_invert_poles = true
		);
    }
    
    //I use two sets of wings
    //short wings to retain the battery aligned
    //Tall wings to clip the battery in place

	difference()
	{
		union()
		{
			//Retaining wing butt
			color("red")
			full_support_18650
			(
				id_18650 / 2,
				it_wall,
				l_total / ilk_wing,
				ia_wing
			);

			//Retaining wing front
			color("red")
			translate([l_total *(1 -1/ilk_wing),0,0])
			full_support_18650
			(
				id_18650 / 2,
				it_wall,
				l_total / ilk_wing,
				ia_wing
			);

			//Retaining wing center
			if (false)
			color("red")
			translate([l_total *(2.5/6),0,0])
			full_support_18650
			(
				id_18650 / 2,
				it_wall,
				l_total / 6,
				ia_wing
			);

			//Support wing
			color("red")
			full_support_18650
			(
				id_18650/2,
				it_wall,
				l_total,
				ia_cradle
			);

			//POSITIVE TAB BUTTON 
			translate([0,0,it_wall])
			battery_18650_contact_holder
			(
				//Size of the cylindrical endcap of the holder
				id_18650_cap = id_18650,
				it_18650_cap = it_cap,
				//Thickness of the material behind the cap
				it_cap_back = it_cap_back,
				//Size of the backplate of the tab with spring, this should include the tollerance
				il_tab = il_tab,
				iw_tab = iw_tab,
				//Size of the spring or button
				it_tab_spring = it_tab_button_positive,
				//Size of the rails where the tab slots in. This should leave space for the spring itself
				iw_tab_rail = iw_tab_rail,
				//Thickness of the plate of the tab with spring, this should include the tollerance
				//There are two tiny inserts to lock the plate and need to slide in
				it_tab = it_tab,
				//Slot carved in the back to expose the plate for soldering
				il_slot_wire = il_slot_wire,
				iw_slot_wire = iw_slot_wire,
				//Show the model of the tab spring
				ib_show_tab = ix_show_tab,
				//Precision of the circle
				ie_error = 0.01
			);

			//NEGATIVE TABSPRING
			translate([l_total,0,it_wall])
			rotate([0,0,180])
			battery_18650_contact_holder
			(
				//Size of the cylindrical endcap of the holder
				id_18650_cap = id_18650,
				it_18650_cap = it_cap,
				//Thickness of the material behind the cap
				it_cap_back = it_cap_back,
				//Size of the backplate of the tab with spring, this should include the tollerance
				il_tab = il_tab,
				iw_tab = iw_tab,
				//Size of the spring or button
				it_tab_spring = il_tab_spring_unloaded,
				//Size of the rails where the tab slots in. This should leave space for the spring itself
				iw_tab_rail = iw_tab_rail,
				//Thickness of the plate of the tab with spring, this should include the tollerance
				//There are two tiny inserts to lock the plate and need to slide in
				it_tab = it_tab,
				//Slot carved in the back to expose the plate for soldering
				il_slot_wire = 5.5,
				iw_slot_wire = iw_slot_wire,
				//Show the model of the tab spring
				ib_show_tab = ix_show_tab,
				//Precision of the circle
				ie_error = 0.01
			);
		}	//End Sum

		union()
		{
			//FRONT
			//Drill from the back space to solder the wire
			translate([0,0,it_wall*1.5/2])
			rotate([0,-90,180])
			linear_extrude(it_cap_back)
			square([it_wall*1.5,iw_slot_wire],center=true);

			//REAR
			//Drill from the back space to solder the wire
			translate([l_total+0.01,0,it_wall*1.5/2])
			rotate([0,-90,0])
			linear_extrude(it_cap_back)
			square([it_wall*1.5,iw_slot_wire],center=true);

		} //End Subtract

	} //End difference
	
}

//----------------------------------------------------------------------------
//	2S 1P
//----------------------------------------------------------------------------

//Instance holder for a signle 18650 battery
module holder_18650_2s1p
(
	//	BATTERY
	//Diameter of the 18650 battery plus tollerance
	id_18650 = 18.4+0.5,
	//Length of the 18650 battery from base to button
	il_18650 = 71.0,

	//	TAB SPRING/BUTTON
	//Dimensions of the tab plate, plus tollerance
	il_tab = 11.0 +0.5,
	iw_tab = 11.0 +0.5,
	//Thickness of plate slot
	it_tab = 1.25,
	//Size of the button of the tab
	it_tab_button_positive = 1.5,
	//Length of the tab spring, uncompressed
	il_tab_spring_unloaded = 8.0,
	//Length of the tab spring, fully compressed
	il_tab_spring_loaded = 3.0,
	//How much to compress the spring 0 = unloaded, 1 = loaded
	ilk_tab_spring_compression = 0.75,
	//Rails
	iw_tab_rail = 1.75,

	//	STRUCTURE
	//Thickness of the Holder walls
	it_wall = 2.0,
	//Length factor of the wings 10 means 1/10 of length. 5 mean 1/5 of length
	ilk_wing = 10,

	//Angle of the cradle where the battery rests
	ia_cradle = 90,
	//Angle of the wings keeping the battery in place
	ia_wing = 110,
	
	//Thickness of the cap plus rails
	it_cap = 4.0,
	//thickness of the cap back
	it_cap_back = 2.0,

	//	WIRE
	//Lentgh of the wire slot
	il_slot_wire = 6,
	//Width of the wire slot
	iw_slot_wire = 5,
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

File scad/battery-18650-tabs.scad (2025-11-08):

// Include necessary modules for shapes
include <libs/shape_cylinder.scad>;
include <libs/shape_truncated_cone_rounded.scad>;

//--------------------------------------------------------------------------------
//	Battery Spring Tab
//--------------------------------------------------------------------------------

/**
 * Module: battery_18650_tab_spring
 *
 * This module creates a 3D model of a spring tab for an 18650 battery. It includes 
 * features like metal plate, locking mechanisms, and holes for electrical contacts.
 *
 * https://it.rs-online.com/web/p/contatti-per-batterie/3247303
 *
 * Parameters:
 * - i_l_plate (number): Length of the metal plate.
 * - i_w_plate (number): Width of the metal plate.
 * - i_t_plate (number): Thickness of the metal plate.
 * - i_l_lock (number): Length of the locking feature.
 * - i_w_lock (number): Width of the locking feature.
 * - i_h_lock (number): Height of the locking feature.
 * - i_d_hole (number): Diameter of holes for electrical contacts.
 * - i_wi_hole (number): Interaxis between holes.
 * - i_h_tab (number): Total height with spring.
 * - i_d_base (number): Base diameter of the spring cone.
 * - i_d_tip (number): Tip diameter of the spring cone.
 * - i_e_precision (number): Precision for circle approximations.
 */
module battery_18650_tab_spring(
    i_l_plate = 11.5,
    i_w_plate = 11.5,
    i_t_plate = 0.5,
    i_l_lock = 2,
    i_w_lock = 1,
    i_h_lock = 1,
    i_d_hole = 1.75,
    i_wi_hole = 8,
    i_h_tab = 8,
    i_d_base = 6,
    i_d_tip = 5,
    i_e_precision = 0.01
) {
    color("#999999")
    difference()
	{
        union()
		{
            // Metal Plate
            translate([0, 0, i_t_plate / 2])
			cube
			(
				[
					i_l_plate,
					i_w_plate,
					i_t_plate
				],
				center = true
			);

            // Spring feature using a truncated cone shape
            translate([0, 0, i_t_plate / 2])
			truncated_cone
			(
				i_r_bot = i_d_base / 2,
				i_r_top_delta = (i_d_tip - i_d_base) / 2,
				i_h = i_h_tab,
				i_r_edge_rounding = i_d_base / 20 
			);

            // Locking features
            let(ap_lock_section =
			[
                [-i_l_lock / 2, 0],
                [i_l_lock / 2, 0],
                [i_l_lock / 2, i_h_lock]
            ])
            for (l_offset = [(i_l_plate / 2 - i_w_lock / 2), -(i_l_plate / 2 - i_w_lock / 2)])
            {
                translate([l_offset, 0, i_t_plate])
				rotate([-90, 180, 90])
				linear_extrude(i_w_lock, center = true)
				polygon(ap_lock_section);
            }
        } // END ADD

        union()
		{
            // Drill holes in the metal plate for electrical contacts
            for (w_offset = [i_wi_hole / 2, -i_wi_hole / 2])
			{
                translate([0, w_offset, 0])
				shape_cylinder
				(
					i_d = i_d_hole,
					i_h = i_t_plate,
					i_e = i_e_precision
				);
			}
        } // END SUB
    } // End difference
} // End Module: battery_18650_tab_spring

//--------------------------------------------------------------------------------
//	HOLDER 
//--------------------------------------------------------------------------------

//Two endcaps have the guides to hold spring contacts that can be soldered
//https://it.rs-online.com/web/p/contatti-per-batterie/3247303
module battery_18650_contact_holder
(
	//Size of the cylindrical endcap of the holder
	id_18650_cap = 18,
	it_18650_cap = 3.5,
	//Thickness of the material behind the cap
	it_cap_back = 1,
	//Size of the backplate of the tab with spring, this should include the tollerance
	il_tab = 11.5,
	iw_tab = 11.5,
	//Size of the spring or button
	it_tab_spring = 8,
	//Size of the rails where the tab slots in. This should leave space for the spring itself
	iw_tab_rail = 1.75,
	//Thickness of the plate of the tab with spring, this should include the tollerance
	//There are two tiny inserts to lock the plate and need to slide in
	it_tab = 1.25,
	//Slot carved in the back to expose the plate for soldering
	il_slot_wire = 6,
	iw_slot_wire = 5,
	//Show the model of the tab spring
	ib_show_tab = false,
	//Precision of the circle
	ie_error = 0.01
)
{
	color("cyan")
    difference()
    {
        union()
        {
            //Cylinder cap
            //rotate and move the cylinder inside the holder
            translate([0,0,id_18650_cap/2])
            rotate([0,90,0])
            //Construct cylinder
			shape_cylinder
			(
				i_d = id_18650_cap,
				i_h = it_18650_cap,
				i_e = ie_error
			);

        }
        //Drill a space for the contacts
        union()
        {
			//Drill the plate
			//if(false)
			translate([it_cap_back,0,id_18650_cap/2])
			rotate([0,-90,180])
			linear_extrude(it_tab)
			square([il_tab,iw_tab],center=true);

			//Drill another plate to reach the top of the cap
			//doesn't need to be precise, just extra drill
			translate([it_cap_back,0,id_18650_cap/2+iw_tab])
			rotate([0,-90,180])
			linear_extrude(it_tab)
			square([il_tab,iw_tab],center=true);

			//Drill the rails that reach the surface 
			translate([it_tab+it_cap_back,0,id_18650_cap/2])
			rotate([0,-90,180])
			linear_extrude(it_18650_cap-it_tab-it_cap_back)
			square([il_tab,iw_tab-2*iw_tab_rail],center=true);

			//Drill another to reach the top of the cap
			translate([it_tab+it_cap_back,0,id_18650_cap/2+iw_tab])
			rotate([0,-90,180])
			linear_extrude(it_18650_cap-it_tab-it_cap_back)
			square([il_tab,iw_tab-2*iw_tab_rail],center=true);

			//Drill from the back space to solder the wire
			translate([0,0,il_slot_wire/2])
			rotate([0,-90,180])
			linear_extrude(it_cap_back)
			square([il_slot_wire,iw_slot_wire],center=true);

			//Add an arc to make it printable without support
			//if (false)
			translate([0,0,il_slot_wire])
			rotate([0,-90,180])
			linear_extrude(it_cap_back)
			circle(d=iw_slot_wire,$fn=40);

        }
    }

	if (ib_show_tab == true)
	translate([it_cap_back*1.1,0,id_18650_cap/2])
	rotate([0,-90,180])
	rotate([0,0,90])
	battery_18650_tab_spring
	(
		//Size of the plate
		i_l_plate = il_tab,
		i_w_plate = iw_tab,
		//Size of the spring and tab
		i_h_tab = it_tab_spring
	);

}

//Cap without tab spring shown
//battery_18650_contact_holder();

//Cap with tab spring shown
//battery_18650_contact_holder(ib_show_tab=true);


// Test the module with specific parameters
//battery_18650_tab_spring();

// Optional: Uncomment to create female and male tabs for testing

if (false)
    battery_18650_tab_spring(
        i_l_plate = 10,
        i_w_plate = 10,
        i_t_plate = 0.1,
        i_l_lock = 2,
        i_w_lock = 1,
        i_h_lock = 1,
        i_d_hole = 1.75,
        i_wi_hole = 8,
        i_h_tab = 8, // Total height with spring
        i_d_base = 6,
        i_d_tip = 5,
        i_e_precision = 0.01
    );

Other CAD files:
scad/battery-18650.scad
scad/hull_lpmu.scad
scad/hull_rpi3.scad
scad/pcb_regulator.scad
src/hull_lpmu.scad

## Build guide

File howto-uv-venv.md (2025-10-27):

# UV INSTALL

```
curl -LsSf https://astral.sh/uv/install.sh | sh

sudo reboot

uv
```

<details>
<summary>UV INSTALL LOG</summary>

```
sona@lpn10016gb:~$ curl -LsSf https://astral.sh/uv/install.sh | sh
downloading uv 0.9.5 x86_64-unknown-linux-gnu
no checksums to verify
installing to /home/sona/.local/bin
  uv
  uvx
everything's installed!

To add $HOME/.local/bin to your PATH, either restart your shell or run:

    source $HOME/.local/bin/env (sh, bash, zsh)
    source $HOME/.local/bin/env.fish (fish)

sona@lpn10016gb:~/test_microphone$ sudo reboot now

sona@lpn10016gb:~$ uv
An extremely fast Python package manager.

Usage: uv [OPTIONS] <COMMAND>

Commands:
  auth     Manage authentication
  run      Run a command or script
  init     Create a new project
  add      Add dependencies to the project
  remove   Remove dependencies from the project
  version  Read or update the project's version
  sync     Update the project's environment
  lock     Update the project's lockfile
  export   Export the project's lockfile to an alternate format
  tree     Display the project's dependency tree
  format   Format Python code in the project
  tool     Run and install commands provided by Python packages
  python   Manage Python versions and installations
  pip      Manage Python packages with a pip-compatible interface
  venv     Create a virtual environment
  build    Build Python packages into source distributions and wheels
  publish  Upload distributions to an index
  cache    Manage uv's cache
  self     Manage the uv executable
  help     Display documentation for a command

Cache options:
  -n, --no-cache               Avoid reading from or writing to the cache, instead using a temporary directory for the duration of
                               the operation [env: UV_NO_CACHE=]
      --cache-dir <CACHE_DIR>  Path to the cache directory [env: UV_CACHE_DIR=]

Python options:
      --managed-python       Require use of uv-managed Python versions [env: UV_MANAGED_PYTHON=]
      --no-managed-python    Disable use of uv-managed Python versions [env: UV_NO_MANAGED_PYTHON=]
      --no-python-downloads  Disable automatic downloads of Python. [env: "UV_PYTHON_DOWNLOADS=never"]

Global options:
  -q, --quiet...                                   Use quiet output
  -v, --verbose...                                 Use verbose output
      --color <COLOR_CHOICE>                       Control the use of color in output [possible values: auto, always, never]
      --native-tls                                 Whether to load TLS certificates from the platform's native certificate store
                                                   [env: UV_NATIVE_TLS=]
      --offline                                    Disable network access [env: UV_OFFLINE=]
      --allow-insecure-host <ALLOW_INSECURE_HOST>  Allow insecure connections to a host [env: UV_INSECURE_HOST=]
      --no-progress                                Hide all progress outputs [env: UV_NO_PROGRESS=]
      --directory <DIRECTORY>                      Change to the given directory prior to running the command [env:
                                                   UV_WORKING_DIRECTORY=]
      --project <PROJECT>                          Run the command within the given project directory [env: UV_PROJECT=]
      --config-file <CONFIG_FILE>                  The path to a `uv.toml` file to use for configuration [env: UV_CONFIG_FILE=]
      --no-config                                  Avoid discovering configuration files (`pyproject.toml`, `uv.toml`) [env:
                                                   UV_NO_CONFIG=]
  -h, --help                                       Display the concise help for this command
  -V, --version                                    Display the uv version

Use `uv help` for more details.

```

</details>

# UV VENV

```
cd test_microphone

uv venv LPMU --python 3.13

source LPMU/bin/activate

python --version
``` 

<details>
<summary>UV VENV LOG</summary>

``` 
sona@lpn10016gb:~/test_microphone$ source LPMU/bin/activate
(LPMU) sona@lpn10016gb:~/test_microphone$ python
Python 3.13.9 (main, Oct 14 2025, 21:29:44) [Clang 20.1.4 ] on linux

(LPMU) sona@lpn10016gb:~/test_microphone$ python --version
Python 3.13.9
``` 

</details>

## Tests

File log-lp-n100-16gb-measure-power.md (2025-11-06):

# Measure power use of Lattepanda Mu N100 16GB

# Latte Panda Mu N100 8GB Ubuntu Desktop 24 Ollama and Screen



| Condition | Voltage | Current | Power |
|---|---|---|---|
| OFF | 18 V | 75 mA | 1.35 W  |
| IDLE OS | 18 V | 406 mA  | 8.28 W  |
| Ollama inference | 18 V | 1.4 A | 25.20 W |

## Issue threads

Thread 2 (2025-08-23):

MEC: Ping Pong Pivot

OrsoEric, 2025-08-23:
Create a 3D printed struct that houses a ping pong ball upside down

This is the pivot support of the robot

OrsoEric, 2025-08-27:
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

gmacario, 2025-08-28:
Ah... after we met and you showed me the assembly I eventually got what this issue was about!

Nice design, indeed!

Closed 2025-08-27.

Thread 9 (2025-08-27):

MEC: Design Servo Holder

OrsoEric, 2025-08-27:
Design pillars to hold the servos

I reused the servo and measure I aldready made

I'm thinking of making stronger vertical pillar without horizontal structures, that's because I print the base in one piece

OrsoEric, 2025-08-27:
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

Closed 2025-08-27.

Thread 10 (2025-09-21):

ELN: Latte Panda Mu

OrsoEric, 2025-09-21:
I got the Lattepanda MU context(https://github.com/B-AROL-O/FREISA/issues/86#issuecomment-3311370214)

OrsoEric, 2025-09-21:
N305 16 GB doesn't work

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

OrsoEric, 2025-09-21:
N100 8GB from Mouser works.

Arrived preinsalled with WIN11

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

OrsoEric, 2025-09-21:
Burn a Ubuntu 24 USB with Rufus, and change BIOS BOOT settings.

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

I got a chealp 256GB 3.0 4X NVMe that had linux crap on it

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

Ubuntu installed on emmc wiping windows

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

Ubuntu 24 works

Closed 2025-09-21.

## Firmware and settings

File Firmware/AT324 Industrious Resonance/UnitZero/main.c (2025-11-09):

/****************************************************************************
**	ROBOTICA@POLITO PROJECT
*****************************************************************************
**	Unit Zero Zero
*****************************************************************************
**	Author: 			Orso Eric
**	Creation Date:
**	Last Edit Date:
**	Revision:			1
**	Version:			0.1 ALPHA
****************************************************************************/

/****************************************************************************
**	HYSTORY VERSION
*****************************************************************************
**	R1 V0.1ALPHA
**		>I wrote a cool function that allow to update servo in one function,
**		i think it's best to update them in sequence to avoid artifact
**		>i rewrote the servo scan function, now it scan the servo in order
**		i eliminated the artifact and greatly reduced var usage and time
**		>added the interpolator function, now servo position is extrapolated
**		from time and points in space and time, offset is accounted for during calculations
**		>global time is now same advancement as servo period
**		~20mS tick, 5.12S longest single movement length
**		>work like a charm
**		>I added the LCD and the trigonometric function library
**		>i moved timer 0 to 156.0uS to update the display and mot is now 156.8*128= 20.07mS
**		>I added progmem capability to the LUT of the trig library to save data memory
**		>tested at_sin8 and at_cos8 by showing them to the display, they seems to work fine
**		>added safe and servo_idle status flags
**		>now the interpolator copy Xe,Te in Xs, Ts when motion end, it setup for next motion and stop the servo
**	V0.2 ALPHA
**		>I vastly improved upon the servo driver. The version I did before
**		is not that user friendly, the user have to meddle with thing to do things.
**		What the user want is to set a position and a speed, and have a flag when 
**		pos is reached. My new driver does just that.
**		The user see three sets of var
**			CONTROL
**			>servo_pos
**			>servo_speed
**			FEEDBACK
**			>servo_lock
**			CONFIG
**			>servo_off
**			>SERVO_MAX_SPEED
**		>Porting to LCD library V3. Here the driver sync the display with a
**		memory. The user can make 1M printchar a second and the driver still
**		won't bug out. Muchbetter abstraction and lower overhead compared
**		to command fifo approach.
**		>Added DPRINTEF macros to at_utils. used in codeblock.
**
**		2025-11-09
**	I'm reporpousing UnitZero firmware 
**	Adding UART and uniparser
****************************************************************************/

/****************************************************************************
**	DESCRIPTION
*****************************************************************************
**	This is the control progam for the 5 servos lego 4 leg robots
*****************************************************************************
**	CALCULATION OF TIMER 1 OCR FOR PULSE WIDTH
**	Constant for the conversion from angle (S8) to OCR (U16)
**	x	= [I8] input angle, i use from -127 to +127, -128 is the disable special code
**	Tn 	= [s] (typ 1.5mS) neutral time of the servo, pulse width required for 0°
**	Td	= [s] (typ 0.9mS) maximum skew of the pulse width, from minimum angle (Tn-Td) to maximum angle (Tn+Td)
**	Tt	= [s] (typ 50nS) N/Fclk width of a single stepof the timer, required to calculate the OCR
**	N	= [1] timer prescaler, 1 maximum precision OCR bigger (might require 16bit), 2^n OCR smaller lower precision require less bits
**	K0	= [1] Tn / Tt neutral value of OCR
**	K1	= [1] Td / Tt / 127 angle constant, multiply angle to obtain OCR, 127 is the maximum value of the input
**	OCR	= K0 + K1 * x, calculation of OCR
**	Example
**	Fclk = 20e6, N = 1, Tn = 1.5mS, Td = 0.9mS, x = [-127,+127]
**	K0 = 30e3, K1 = 142 (141.7), >>>OCR = 30e3 + x*142<<<
**	SERVO OFFSET:
**	This is the correction for the 0 position, it is added during the caluclation
**	and does not eat into the servo position range
**	JOINTS:
**	Index		|	Joint		|	Increase position move toward what?
**	-------------------------------------------------------------------
**	0			|	front DX	|	front
**	1			|	front SX	|	back
**	2			|	rear SX		|	back
**	3			|	rear DX		|	front
**	4			|	front hip	|	rise 0, lower 1
**	5			|	rear hip	|	rise 3, lower 2
*****************************************************************************
**	INTERPOLATOR
**	Above the timing ISR for the servo there is the interpolator that generate the positions
**	The user write the wished positions and times in the following global vars
**		Xs	Ts	Xe	Te
**	0
**	...
**	5
**	The time is in tick unit (about 80mS), example:
**	servo_global_time = 45 		//i'm in the 45° tick of the cycle
**	SERVO_POS( 0 , 3 ) = -50	//i start the new motion from current time and in position -50 (50/127*90°=-35.4°)
**	SERVO_TIME( 0 , 3 ) = 45
**	SERVO_POS( 1 , 3 ) = -30	//i end the new motion in 480mS and in position -30 (50/127*90°=-21.3°)
**	SERVO_TIME( 1 , 3 ) = 45+6
**	The interpolator is a powerful function, allow for much easier high level motion generation
**	since it handle all the complexity of sub angle calculation and the timing routine
**	handle all the complexity of the time generations
****************************************************************************/

/****************************************************************************
**	USED PIN
**	TIPS: compile this field before writing any code: it really helps!
*****************************************************************************
**	PB0			|	SERVO 0 - Wheel RX
**	PB1			|	SERVO 1 - Wheel LX
**	PB2			|	
**	PB3			|	
**	PB4			|	
**	PB5			|	
**	PB6			| 	
**	PB7			|	SERVO 7
**	
**	PD0			|	UART0 RXI
**	PD1			|	UART0 TX0
**	PD2			|	L
*****************************************************************************
**
****************************************************************************/

/****************************************************************************
**	USED PHERIPERALS
**	TIPS: compile this field before writing any code: it really helps!
*****************************************************************************
**	HS-311 Servo
**	Voltage		|	5.0
**	Current		|	7m (idle)		160m (free)		700m (stall)
**	Torque		|	3 [Kg*cm]		294 [mNm]
**	Angle		|
**	Control		|	1.5mS (center)	+/-900uS (90°)	~20mS (period)
**				|	HZ -> no force
**				|	positive DT -> clockwise direction
**	UART		| 
*****************************************************************************

**
****************************************************************************/

/****************************************************************************
**	KNOWN BUG
*****************************************************************************
**	>
****************************************************************************/

/****************************************************************************
**	TODO
*****************************************************************************
**
****************************************************************************/

/****************************************************************************
**	ENVROIMENT VARIABILE
****************************************************************************/

/****************************************************************************
**	INCLUDE
**	TIPS: ".h" should not include other ".h", it lower the leggibility of the code
**	TIPS: ".h" must not contain anything that generate code, write only declaration or prototype
**	this help the leggibility and the debug phase
**	TIPS: type from the stdint.h have a well defined width and signedness, use them
**	( uint8_t = unsigned 8 bit, int8_t = signed 8 bit, uint32_t = unsiged 32 bit, ecc... )
****************************************************************************/

#include "global.h"

/****************************************************************************
**	DEFINE
****************************************************************************/

//define for the mail loop
#define EVER (;;)

/****************************************************************************
**	MACRO
****************************************************************************/

/****************************************************************************
**	STRUCTURE
****************************************************************************/

/****************************************************************************
**	PROTOTYPE: FUNCTION
**	TIPS: use "extern" in function prototype, it's not necessary, but any other
**	prototype need it, it help the leggibility of the code
****************************************************************************/

extern U8 seesaw();

/****************************************************************************
**	PROTOTYPE: GLOBAL VARIABILE
****************************************************************************/

/****************************************************************************
**	GLOBAL VARIABILE:
**	TIPS: "const" variabile will be loaded in the flash memory, saving the ram,
**	use it for string that will not be modified
**	TIPS: if you want a ISR to manipulate a global variabile, than that variabile
**	**must** be declared "volatile" so that the c compiler will not wipe out the
**	variabile by optimising the code, use that variabile as less as possibile
**	because it will not be optimised
**	TIPS: "volatile int" variabile may give problem, don't use it (uP is 8 bits, while
**	int is 16 bits, it's implemented by concatenating 2 byte, the volatile statement
**	disable the optimisation on that variabile, and mess up that code)
****************************************************************************/

	//-----------------------------------------------------------------------
	//	STATUS VARS
	//-----------------------------------------------------------------------

//Those are the flags updated by ISRs
volatile Isr_flags f;
//Status variabile for the servos, keep track of which servo to do next
volatile U8 servo_cnt	= N_SERVOS;

	///----------------------------------------------------------------------
	///	BUFFERS
	///----------------------------------------------------------------------
	//	Buffers structure and data vectors

//Safe circular buffer for UART input data
volatile At_buf8_safe uart_rx_buf;
//Safe circular buffer for uart tx data
At_buf8 uart_tx_buf;
//allocate the working vector for the buffer
U8 v0[ UART_RX_BUF_SIZE ];
//allocate the working vector for the buffer
U8 v1[ UART_TX_BUF_SIZE ];

	//-----------------------------------------------------------------------
	//	SERVOS VARS
	//-----------------------------------------------------------------------

//One flag per servo. '1' if the servo is keeping up with target_pos
U8 servo_lock			= 0x00;
//Current position of the servos. Used by the driver, user should not write here
U16 servo_delay[ N_SERVOS ];
//Target position. The user write here, the driver will do it's best to reach it
S8 servo_target_pos[ N_SERVOS ];
//The servo will rotate at this speed [unit/second]
U8 servo_target_speed[ N_SERVOS ];
//servo position offset for true 0 position
//offsets are accounted for in separately from the position, it does not eat into the dynamic
S8 servo_off[ N_SERVOS ];

	//-----------------------------------------------------------------------
	//	TRAJECTORY VARS
	//-----------------------------------------------------------------------

//Timebase for trajectory generation. 1 time unit = 1/50Hz.
U16 servo_global_time 	= 0;
//Current motion plan
//Trajectories trajectory = MOVE_IDLE;

/****************************************************************************
**	MAIN
****************************************************************************/

int main( void )
{
	///**********************************************************************
	///	LOCAL VARIABILE
	///	TIPS: main local variabile last the entiere program, but unlike the global variabile,
	///	they are not visible from other function, the c compiler can better optimize them
	///**********************************************************************

	//temp vars
	U8 u8t;
	U16 u16t;
	//S8 s8t;

	U8 pre_traj = 0;

	///**********************************************************************
	///	VARIABILES INITIALISATION
	///**********************************************************************
	
		///UART RX BUFFER INIT
	//I init the rx and tx buffers
	//attach vector to buffer
	AT_BUF_ATTACH( uart_rx_buf, v0, UART_RX_BUF_SIZE);
	//attach vector to buffer
	AT_BUF_ATTACH( uart_tx_buf, v1, UART_TX_BUF_SIZE);
	
	//Clear global servo time
	//Initialize servo position to zero (offset is accounted for during calculations, i must not add it here)
	for (u8t = 0;u8t < N_SERVOS;u8t++)
	{
		servo_off[u8t]			= +0;
		servo_delay[u8t] 		= K0;	//Servo true position
		servo_target_pos[u8t] 	= +0;	//Servo targt position (user)
		servo_target_speed[u8t]	= MOVE_SPEED;	//Servo target speed (default)
	}

	///**********************************************************************
	///	PHERIPERALS INITIALISATION
	///**********************************************************************

	//Initialize devices
	global_init();
	//The proud name of this unit
	lcd_print_str( LCD_POS(0,0), (U8 *)"Unit Zero");
	lcd_print_str( LCD_POS(1,0), (U8 *)"Time:");

	///**********************************************************************
	///	MAIN LOOP
	///**********************************************************************

	for EVER
	{
		//-----------------------------------------------------------------------
		//	LCD DIPSPLAY UPDATE
		//-----------------------------------------------------------------------
		//	call the lcd display driver

		//If: update the LCD display (10KHz)
		if (f.lcd_update == 1)
		{
			f.lcd_update = 0;
			//Update display
			lcd_update();
		}

		//-----------------------------------------------------------------------
		//	START MOTOR SCAN (5.8uS max all servo functions)
		//-----------------------------------------------------------------------
		//	Flag rised by [Timer 0]
		//	>activity pin (led signal uC use, oscilloscope allow to measure function times)
		//	>clear servo status var
		//	>calculate first delay, pull down first line
		//	>setup first delay, enable [Timer 1]
		//	>Timer 1 ISR will handle the update of the servos and disable it self when done

		//If: Start Servo Scan (50Hz)
		if (f.servo_scan == 1)
		{
			//clear flag
			f.servo_scan = 0;
				//Startup the servo scan
			//clear status var
			servo_cnt 	= 0;
			//calculate delay
			u16t		= servo_calc_delay( 0 );
			//Store delay on T1
			OCR1A 		= u16t;
			//start T1
			START_TIMER1();
			//pull up first line
			SET_BIT( SERVO_PORT, 0 +SERVO_PIN_OFFSET );
				//Advance global time by one tick
			servo_global_time++;
			lcd_print_u16( LCD_POS(1,6), servo_global_time );

			pre_traj = AT_TOP_INC( pre_traj, MOVE_STEP_TIME );
			if (pre_traj == 0)
			{
				f.servo_traj = 1;
			}
			
			
			
			
		}	//End If: motor scan flag

		//-----------------------------------------------------------------------
		//	TRAJECTORY GENERATION
		//-----------------------------------------------------------------------

		if (f.servo_traj == 1)
		{
			f.servo_traj = 0;
			
			//Debug send via UART
			AT_BUF_PUSH( uart_tx_buf, 'Z' );
			//TOGGLE_BIT( PORTD, PD1 );
			
			//Toggle LED
			TOGGLE_BIT( PORTC, PC0 );
			
			seesaw();
			
			
			/*
			//fetch global time
			u16t = servo_global_time;
			if ((u16t & 0x00ff) == 0x0000)
			{
				//Initialize servo position to zero (offset is accounted for during calculations, i must not add it here)
				for (u8t = 0;u8t < N_SERVOS;u8t++)
				{
					servo_target_pos[u8t] 	= +20;	//Servo targt position (user)	
				}
			}
			else if ((u16t & 0x00ff) == 0x0080)
			{
				//Initialize servo position to zero (offset is accounted for during calculations, i must not add it here)
				for (u8t = 0;u8t < N_SERVOS;u8t++)
				{
					servo_target_pos[u8t] 	= -20;	//Servo targt position (user)	
				}
			}
			*/
			
			///----------------------------------------------------------------------
			/// UART RX
			///----------------------------------------------------------------------
			//	Handle RX from RS232
			//	Loopback

			//if: uart rx buffer is not empty
			if ( AT_BUF_NUMELEM( uart_rx_buf ) > 0)
			{
				///Get data
				//Get the byte from the RX buffer (ISR put it there)
				u8t = AT_BUF_PEEK( uart_rx_buf );
				AT_BUF_KICK_SAFER( uart_rx_buf );
				///Loopback
				//Push into tx buffer
				AT_BUF_PUSH( uart_tx_buf, u8t );
			}
			
			///----------------------------------------------------------------------
			/// UART TX
			///----------------------------------------------------------------------

			//if: the Uart0 HW buffer is empty and the UART tx buffer is not empty
			if ( (UART0_TX_READY()) && (AT_BUF_NUMELEM( uart_tx_buf ) > 0) )
			{
				//Get the byte to be filtered out
				u8t = AT_BUF_PEEK( uart_tx_buf );
				AT_BUF_KICK( uart_tx_buf );
				//Write on UART tx buffer.
				UDR0 = u8t;

				//lcd_print_char( LCD_POS( 1, 14), u8t );
			}	//End If: uart tx
		}
	}	//end for: for EVER

	return 0;
}	//end main

/****************************************************************************
** FUNCTION:
****************************************************************************/

U8 seesaw()
{
	//static U8 u8_cnt = 0;
	static U8 u8_dir = 0;
	
	servo_target_speed[0] = 5;
	
	if (u8_dir == FALSE)
	{
		servo_target_pos[0] += 1;
		if (servo_target_pos[0]>=10)
		{
			u8_dir = TRUE;
		}
	}
	else
	{
		servo_target_pos[0] -= 1;
		if (servo_target_pos[0]<=-10)
		{
			u8_dir = FALSE;
		}
	}
	
	servo_target_pos[1] = servo_target_pos[0];
	
	return 0;
}


/****************************************************************************
**	SERVO CALC POS
*****************************************************************************
**	This function will calculate the delay that move servo[index] closer to the target position
**		SLEW RATE LIMITER: The function will only move at the speed set by the user
**		OFFSET CORRECTION:	In this function i account for mechanical misalignement
**	Formula:
**	xpos = xtarget if ABS(xtarget -xpos) < xspeed/50
**	delay[OCR] = K0 + K1*xoff + K1*xpos
****************************************************************************/

U16 servo_calc_delay( U8 index )
{
	///--------------------------------------------------------------------------
	///	STATIC VARIABILE
	///--------------------------------------------------------------------------

	///--------------------------------------------------------------------------
	///	LOCAL VARIABILE
	///--------------------------------------------------------------------------

	U16 delay;

	S16 slew_rate;

	S16 s16t;

	U16 ret;

	///--------------------------------------------------------------------------
	///	CHECK AND INITIALIZATIONS
	///--------------------------------------------------------------------------

	///--------------------------------------------------------------------------
	///	BODY
	///--------------------------------------------------------------------------
	//	>Calculate target delay
	//	>Calculate maximum delay change target_delay-old delay (slew rate)
	//		>based on user defined target_speed 
	//		>limited by servo max slew rate (max rotation speed normalized to my units)
	//	>calculate new delay (apply delay change)
	//	>save delay on servo_delay
	//	>return new delay
		///Calculate target OCR of servo [index]
	//Calculate position dependent coefficient
	s16t 	= K1 *servo_off[ index ] +K1 *servo_target_pos[ index ];
	//apply sign correction
	if (IS_BIT_ONE( SERVO_DIR, index ))
	{
		s16t = -s16t;
	}
	delay	= K0 + s16t;
		///Speed Limiter
	//calculate maximum allowed motion. I need to convert from [unit/second] -> [unit/20mS]
	slew_rate = K1*servo_target_speed[ index ] /50;
	//If: The user wants to exceed the servo limits
	if (slew_rate > SERVO_MAX_SLEW_RATE)
	{
		//Clip the Slew rate
		slew_rate = SERVO_MAX_SLEW_RATE;
	}
	//calculate slew rate required to meet user input
	s16t = delay - servo_delay[ index ];
	if (s16t > +slew_rate)
	{
		//I'm NOT locked: the servo is moving at max speed
		CLEAR_BIT( servo_lock, index );
		ret = servo_delay[ index ] +slew_rate;
	}
	else if (s16t < -slew_rate)
	{
		//I'm NOT locked: the servo is moving at max speed
		CLEAR_BIT( servo_lock, index );
		ret = servo_delay[ index ] -slew_rate;
	}
	else
	{
		//I'm locked: The motor is not moving at max speed
		SET_BIT( servo_lock, index );
		ret = delay;
	}
	//Write back result and return the delay
	servo_delay[ index ] = ret;

	///--------------------------------------------------------------------------
	///	RETURN
	///--------------------------------------------------------------------------	

	return ret;
}	//end function: servo_calc_delay

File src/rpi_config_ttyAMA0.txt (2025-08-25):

# For more options and information see
# http://rptl.io/configtxt
# Some settings may impact device functionality. See link above for details

# Uncomment some or all of these to enable the optional hardware interfaces
#dtparam=i2c_arm=on
#dtparam=i2s=on
#dtparam=spi=on
# Enable UART0/ttyAMA0 on GPIO 14 & 15
dtparam=uart0           

# Enable audio (loads snd_bcm2835)
dtparam=audio=on

# Additional overlays and parameters are documented
# /boot/firmware/overlays/README

# Automatically load overlays for detected cameras
camera_auto_detect=1

# Automatically load overlays for detected DSI displays
display_auto_detect=1

# Automatically load initramfs files, if found
auto_initramfs=1

# Enable DRM VC4 V3D driver
dtoverlay=vc4-kms-v3d
max_framebuffers=2

# Don't have the firmware create an initial video= setting in cmdline.txt.
# Use the kernel's default instead.
disable_fw_kms_setup=1

# Run in 64-bit mode
arm_64bit=1

# Disable compensation for displays with overscan
disable_overscan=1

# Run as fast as firmware / board allows
arm_boost=1

[cm4]
# Enable host mode on the 2711 built-in XHCI USB controller.
# This line should be removed if the legacy DWC2 controller is required
# (e.g. for USB device mode) or if USB support is not required.
otg_mode=1

[all]

dtparam=pciex1_gen=3
dtparam=uart0=on

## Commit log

2025-08-23 https://github.com/OrsoEric/robot-ros2-Industrious-Resonance/issues/4 Tested OrangeHat. TODO: move motors and test UART but I need the OS for that.
2025-08-23 serial working
    [rpi_config_old.txt, rpi_config_ttyAMA0.txt]
2025-08-25 come up with the hull shape and creating the script to make it. I'll use the might of Flux and Hunyuan to make the shell!
    [hull.scad]
2025-08-27 https://github.com/OrsoEric/robot-ros2-Industrious-Resonance/issues/7
    Started OpenSCAD design of the functional base
    Started artworks for the Shell
    [ball_holder.scad, battery-18650.scad, hs422-servo.scad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]
2025-08-27 https://github.com/OrsoEric/robot-ros2-Industrious-Resonance/issues/2
    Made the prototype for the pivot ball holder, since I have spare 40mm tennis balls.
    [2025-08-27_T1046_test-ball-holder-40mm.stl, 2025-08-27_T1304_test-ball-holder-40mm.stl, ball_holder.scad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]
2025-08-27 https://github.com/OrsoEric/robot-ros2-Industrious-Resonance/issues/2 Pivot printed and working!
    [hull.scad]
2025-08-27 https://github.com/OrsoEric/robot-ros2-Industrious-Resonance/issues/9
    Printed the servo pillar and worked out tollerances, it should be good
    [hull.scad, test_servo_holder_a.stl, test_servo_holder_b.stl]
2025-08-27 https://github.com/OrsoEric/robot-ros2-Industrious-Resonance/issues/9
    Pillars are designed
    I shrunk the platform to fit the printer and am doing the first iteration with just servo and pivot
    Next I am looking to add the rpi, the raspicam, the shell and the battery
    [hull.scad, test-hull-norpi-nobat-a.stl]
2025-09-21 add images.
    [hull.scad]
2025-10-26 Installing second Latte Panda board, N100 16GB
2025-11-02 https://github.com/OrsoEric/robot-ros2-Industrious-Resonance/issues/15
    measure power use of N100 8GB with desktop OS and screen
2025-11-06 Changing shape, and doing lots of work on layout https://github.com/OrsoEric/robot-ros2-Industrious-Resonance/issues/20
    [battery-18650-holder.scad, battery-18650-tabs.scad, battery-18650.scad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]
2025-11-06 https://github.com/OrsoEric/robot-ros2-Industrious-Resonance/issues/7 Great progress, reshaped, added SBC LPMU tested battery holder TODO: I need to add a voltage controller, and a microcontroller fo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
    [battery-18650-holder.scad, hull_lpmu.scad, sbc_lattepanda_mu_lite_board.scad]
2025-11-07 added screenshots added library for donut with square section fixed some issues with wheel of hs422 TODO: I should improve the library using the libraries with precision I'm properly sizing the wheel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
    [hull_lpmu.scad]
2025-11-07 I'm working on HS422 support I'm adding the chirality of the hub left and right I'm recentering to place the zero at the baring to make the robot easier to construct THe zero must be at the center ou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
    [hull_lpmu.scad]
2025-11-07 implemented chirality for the HS422 model i_x_right
    [hull_lpmu.scad]
2025-11-07 fixed the pillar geometry, now handles both chirality. added a parameter to set distance from pillar to wheel so it doesn0t scrape i_lm_pillar_wheel
    [hull_lpmu.scad]
2025-11-07 now the servo pillar primitive includes servo and wheel showing it is aligned with zero at center wheel simplifying wheel cutouts
    [hull_lpmu.scad]
2025-11-07 fixed geometry of wheels of robot. TODO: add a width margin to align the wheel cutout
    [hull_lpmu.scad]
2025-11-07 added margin to make the wheel hole closer to the pillar and compensate for bearing. wm_wheel
    [hull_lpmu.scad]
2025-11-07 adjusted the ball holder to comply with thinner base. this also gives more clearance to the ball
    [hull_lpmu.scad]
2025-11-07 fixed pivot ball geometry, and computed clearance and height of servos
    [hull_lpmu.scad]
2025-11-07 changed color of base.
    [hull_lpmu.scad]
2025-11-08 Documented improvements to the platform - LPMU - Shape and bigger - Servo pillar servo and wheel - Ball holder
    https://github.com/OrsoEric/robot-ros2-Industrious-Resonance/issues/7
    [hull_lpmu.scad]
2025-11-08 integrated inverted battery holder and fixed wire passage
    [battery-18650-holder.scad, hull_lpmu.scad]
2025-11-08 adjusted dimensions
    [hull_lpmu.scad]
2025-11-08 Reorked the SBC pillars. Now I have the nuts on the bottom of the base. New primitive shapes.
    [hull_lpmu.scad]
2025-11-08 modeled the 5V voltage regulator and added bolts.
    [hull_lpmu.scad, pcb_regulator.scad]
2025-11-09 Added walls to the base, added hole for the switch. Ready for printing!
    [2025-11-08-T1355_robot.stl, hull_lpmu.scad]
2025-11-09 Printed platform assembled batteries and regulators test fitting all passed :3
    https://github.com/OrsoEric/robot-ros2-Industrious-Resonance/issues/20
    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
2025-11-09 Printed and assembled
    PETG 6h print
    Tested battery holder and regulator
    Perfect so far!
    https://github.com/OrsoEric/robot-ros2-Industrious-Resonance/issues/22
2025-11-09 Tried to install the toolchain for Longan Nano, it's bricked -.-
    I can probably figure it out but it's faster to use another board.
    https://github.com/OrsoEric/robot-ros2-Industrious-Resonance/issues/23
2025-11-09 I installed microchip studio https://www.microchip.com/en-us/tools-resources/develop/microchip-studio#Downloads
    I took my Unit Zero AT324 LCD Servo board that has everything that I need for this robot, it already has the adapter for the servos
    I tried to recompile and flash the firmware and it works!
    I get LCD, and Servos.
    I tested powering from the robot regulator at 17V and I power both microcontroller and servos
    TODO:
    I need a serial connection
    I need the parser
    I need an application to do the serial piloting
    Then I need to link it up with the Lattepanda
    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
    [at_lcd.h]
2025-11-09 video of servo running I tested a position servo and it moves at controlled angle as expected.
2025-11-09 Modified Unit Zero firmware to have - uart driver - uart interrupt - circular buffers - main logic to link the vars - main code for loopback and send dummy z periodically
    Had issues with windows being incompetently designed and refusing to run the drivers of my USB to serial chips -.-
    Found a driver for FTDI that is windows blessed
    Checked with scope
    Tested on computer
    https://github.com/OrsoEric/robot-ros2-Industrious-Resonance/issues/24
    [at_lcd.h]
2025-11-09 Calibrated speed. Removed Unit Zero Trajectory. Fixed direction of motors. Tested seesaw speed of left and right motor. Position 10 mean sow to modest speed.
    https://github.com/OrsoEric/robot-ros2-Industrious-Resonance/issues/26
    [global.h, main.c]
2025-11-13 video of servos moving.
